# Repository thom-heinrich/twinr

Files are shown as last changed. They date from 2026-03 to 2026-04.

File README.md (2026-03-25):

**WHAT**

*TWINR* is an AI Agent for senior citizens; fully open-source, aiming to make AI accessible to people who would really profit of it. 
*TWINR is heavy WIP, but already working if you do some tinkering. I would love to have new contributors*

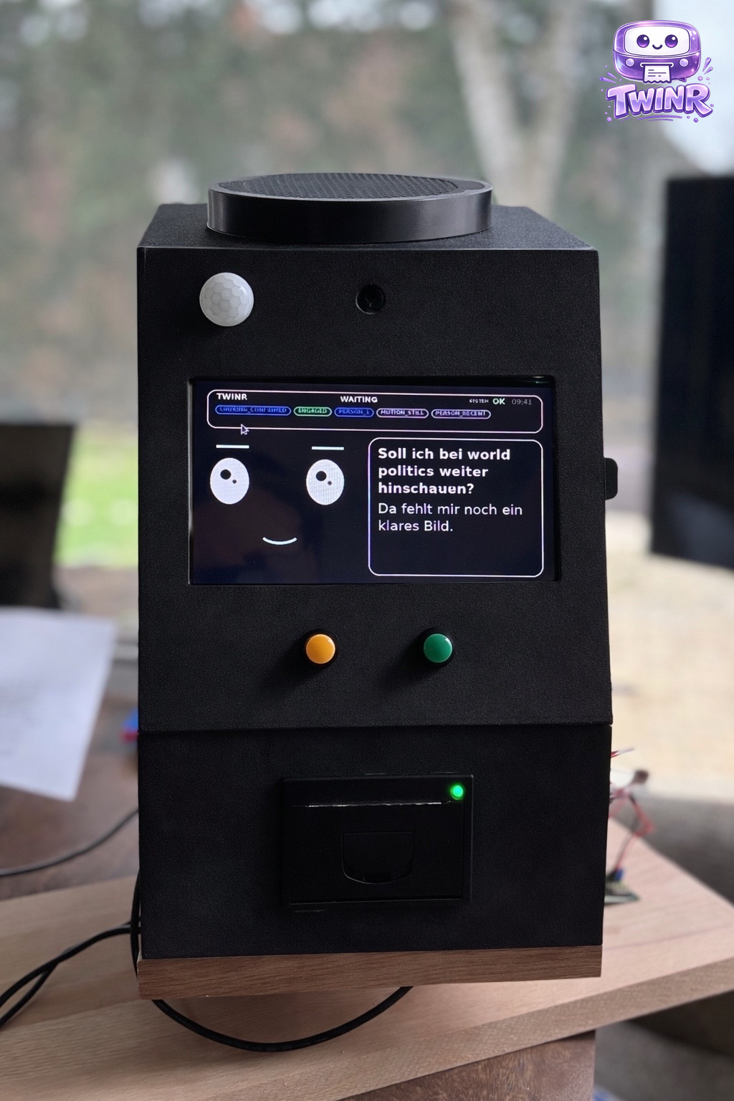
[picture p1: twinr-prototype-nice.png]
twinr-prototype-nice

(You can find the completely unedited picture here --> twinr-prototype.jpeg)

**WHY**

Due to a sad personal event, I spent the last two weeks 24/7 with my mother who is really not tech-savy at all. Okay, tbh - she does not know how to start a computer or use a smart phone - so the web, AI, everything we use daily in our bubble is out of reach to her. 
However: She has so many questions and small tasks an AI Agent could handle easily - plus she loves to use her Alexa, as it is controlled by voice and thus natural to communicate with… but, as we all know, it is limited in it’s capabilities.

**MISSION**

The goal is simple: *Make a voice controlled agent that is as non-digital, as haptic and as accessible as possible*.

**CONTRIBUTE**

So if you are a builder, UX person, maker… and want to join add me on LinkedIn or write to th@arculae.com … if you are not, but you think this is cool, *just share the repo*.

---

**CAPABILITIES**

Twinr is not just a voice wrapper. This repo spans embodied interaction, multimodal perception, memory, automations, integrations, self-programming, operator tooling, and Raspberry-Pi deployment.

- Embodied multi-modal interaction: voice, physical buttons, camera, motion sensing, paper output, display feedback, and optional body movement in one agent stack
- Transcript-first live voice pipeline with follow-up listening, spoken replies, and web-backed question answering
- Physical output layer with speech, thermal printer notes, animated HDMI face UI, and optional servo-based user-following
- Multimodal sensing built around Pi AI Camera, ReSpeaker XVF3800, PIR motion, VAD, and bounded event fusion
- Presence, attention, engagement, and cautious incident cues derived from sensor fusion instead of one-off single-signal hacks
- Proactive companion behaviors that can notice return, stillness, showing intent, or possible distress without defaulting to annoying chatter
- Visual understanding for “look at this” moments, gesture-aware interaction, and camera-assisted embodied UX
- Adaptive memory stack with rolling on-device context, explicit remembered facts, reminders, and optional long-term ChonkyDB memory
- Automation engine for scheduled routines, sensor-triggered actions, printed briefings, and LLM-generated recurring jobs
- Experimental self-programming / Adaptive Skill Engine for compiling reviewed, sandboxed new skills and automations
- Integration-ready architecture for email, calendar, messaging, smart home, and future external systems
- WhatsApp prototype channel plus a broader communications roadmap across TWINR-to-TWINR and TWINR-to-device links
- Caregiver and operator dashboard for devices, memory, automations, system health, logs, and personality management
- Raspberry-Pi hardware operations layer for display, audio, printer, camera, PIR, servo, deployment, and acceptance testing
- Open-source prototype-body 3D-print files and state sound assets included directly in the repo for fast physical iteration

**ROADMAP**

- TWINR App Store with voice discovery and voice-guided installation of reviewed skills
- Real-time TWINR-to-TWINR and TWINR-to-device audio/video communication
- Android and iPhone companion app for family members, caregivers, and operators
- Integration with health trackers and connected health devices
- Proactive companion mode that stays supportive without becoming intrusive or annoying
- Integrated autonomous indoor drone based on Crazyflie for wellbeing checks and other supportive tasks

---

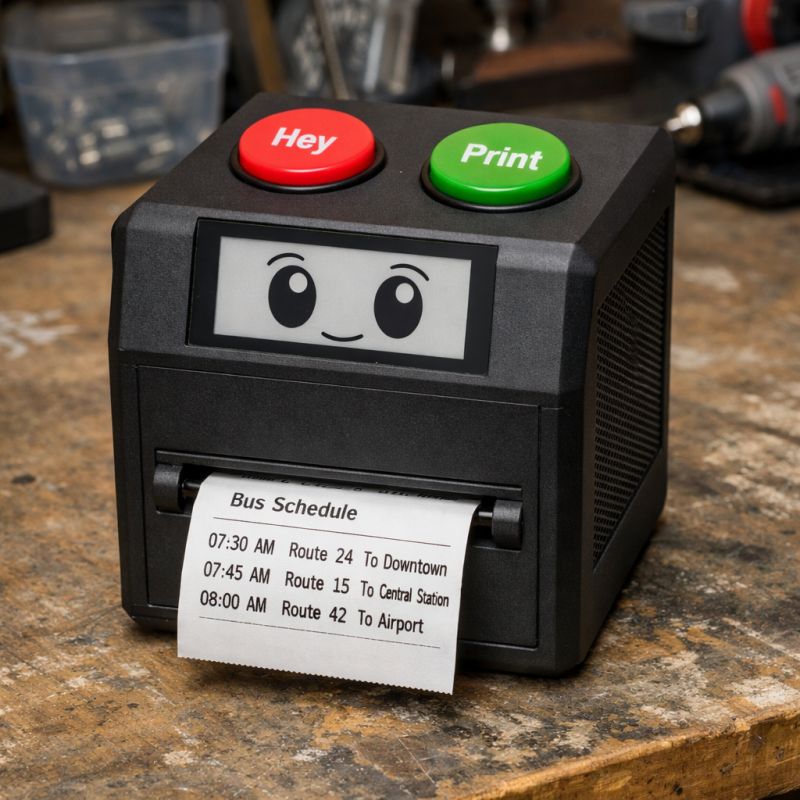
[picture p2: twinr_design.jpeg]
twinr-design


*This is how I imagine TWINR to look in the second or third iteration*

**PROTOTYPE ASSETS**

This repo already includes a few practical prototype assets:

- `3dprint/` contains simple prototype-body parts as `.stl` and `.scad` files, including `main_panel`, `top_panel`, `respeaker`, and `thermal_printer`
- `media/` contains basic state sounds such as `boot.mp3` and `waiting.mp3`

**SHOPPING LIST**

*TWINR Hardware (current prototype direction)*

*Core compute and sensing*

1 x Raspberry Pi 4 or newer

1 x microSD card or SSD for OS, runtime state, and artifacts

1 x Raspberry Pi AI Camera (IMX500) for person, gesture, and presence-related vision

1 x PIR motion sensor with 3.3V-safe GPIO output

2 x buttons (I used 12mm SPST-NO from Same-Sky)

*Audio and feedback*

1 x ReSpeaker XVF3800 4-Mic Array as the main microphone/audio front-end

1 x small speaker compatible with your chosen ReSpeaker playback path

1 x 4" HDMI mini-screen for Twinr's animated face and status UI

1 x thermal printer (DFRobot DFR0503-EN / GP-58-compatible path)

1 x dedicated 9-24V / 2.5A power supply for the thermal printer

*Optional body movement*

1 x digital servo for body rotation; my prototype uses a 360-degree 20 kg model

1 x servo controller / driver, preferably a Pololu Mini Maestro

*Power and build extras*

Optional: a DC-DC converter / buck converter for cleaner power distribution inside the body

Optional: a separate helper Pi if you want to offload the AI-camera or servo path

Plenty of jumper wires, Dupont leads, USB cables, power leads, cable clamps / terminals, and general mounting hardware

Optional: 3D-printed body parts from `3dprint/`

The repo still contains an older Waveshare 4.2" e-paper path for a more minimal build, but the richer current prototype direction is centered on HDMI, Pi AI Camera, ReSpeaker audio, and optional body rotation.

---

**POWER & SAFETY**

For the richer HDMI + camera + audio + printer build, clean power and careful wiring matter a lot more than in the earliest minimal prototype.

- Power the Raspberry Pi through its normal USB-C input with a stable `5V / 3A+` supply
- Give the thermal printer its own `9-24V` supply; do not try to run it from Pi GPIO or weak USB power
- Give a large body servo its own supply matched to the servo vendor spec; do not power a `20kg` servo from the Pi
- If you distribute power inside the body from one larger source, use proper regulators / buck converters for the separate rails instead of improvised direct taps
- Never feed more than `3.3V` into Raspberry Pi GPIO pins
- Share ground where control signals need a common reference, for example Pi and PIR, or Pi / Maestro / servo supply
- Disconnect power before rewiring, double-check polarity before first boot, and secure cables so movement does not pull on GPIO or CSI connectors
- Treat brownouts, random reboots, printer glitches, and twitching servos as likely power-distribution problems first

**HOW TO WIRE**

The current prototype direction is centered on a Raspberry Pi, HDMI mini-screen, ReSpeaker XVF3800 audio, Raspberry Pi AI Camera, two buttons, PIR motion sensing, a thermal printer, and an optional body-rotation servo. The older e-paper path still exists in the repo, but it is no longer the best default for the richer embodied prototype.

See also: [docs/WIRING_DIAGRAM.md](./docs/WIRING_DIAGRAM.md) for a compact Markdown diagram of the current wiring layout.

*1. Prepare the Raspberry Pi*

Install Raspberry Pi OS first. A microSD card is the easiest starting point, though SSD boot also works on recent Pi setups. Before mounting everything into the body, do at least one bench boot with network, keyboard, and screen attached so you can confirm the base system is healthy.

*2. Connect the HDMI mini-screen*

Connect the display to one of the Pi's HDMI outputs with the cable or adapter your screen requires. Many small HDMI screens also need separate `5V` power over USB; if yours does, power it from a suitable regulated `5V` line rather than assuming HDMI alone is enough. Mount the screen so it is readable head-on and leave enough slack in the HDMI cable that opening the body later does not stress the port.

*3. Connect the Raspberry Pi AI Camera*

Connect the Pi AI Camera to the Pi's CSI camera connector with the correct ribbon cable orientation and lock the connector before powering up. Do not hot-plug the camera ribbon. Mount the camera facing forward with a stable field of view, because Twinr uses this path for person, gesture, attention, and presence-related cues.

*4. Connect the ReSpeaker XVF3800 and speaker*

Connect the ReSpeaker XVF3800 to the Pi through its supported USB path so Twinr can use it as the main microphone/audio front-end. Then connect a compatible speaker or powered speaker path for playback. The exact speaker wiring depends on your ReSpeaker board variant: some setups want a powered speaker or small amplifier stage, so do not assume the board can safely drive an arbitrary passive speaker directly. If you prefer, Twinr can also keep ReSpeaker as the microphone path while using a different playback sink such as HDMI audio.

*5. Connect the two buttons*

Use the buttons as simple GPIO inputs with the Pi's internal pull-ups.

Current Twinr mapping:

- Green / "Hey" button: one side to `GPIO23` (`physical pin 16`)
- Yellow / "Print" button: one side to `GPIO22` (`physical pin 15`)
- The other side of both buttons goes to `GND`

No external resistor is required when the software uses the normal pull-up configuration. Do not connect these button inputs to `5V`.

*6. Connect the PIR motion sensor*

Current Twinr prototype mapping:

- `OUT -> GPIO26` (`physical pin 37`)
- `GND -> GND`
- `VCC ->` the supply voltage required by your PIR module

Software defaults assume `active_high=true` and `bias=pull-down`. The signal presented to the Raspberry Pi must stay at or below `3.3V`. If your PIR module is not explicitly GPIO-safe, add level shifting before connecting it to the Pi.

*7. Connect the thermal printer*

For the current printer path, connect the DFRobot `DFR0503-EN` to the Pi over USB and power it from its own external `9-24V / 2.5A` supply. Keep printer power physically separate from the Pi's GPIO power pins. USB carries the data path; the external supply handles the real heating and paper feed load.

*8. Optional: connect the body-rotation servo*

There are two practical paths:

- Preferred path: use a `Pololu Mini Maestro` as the servo controller. Connect the Maestro to the Pi over USB, switch it into `USB_DUAL_PORT`, then connect the servo to the Maestro rather than directly to the Pi. Power the servo from its own supply matched to the servo's requirements.
- Simpler direct path: connect servo `SIG -> GPIO18` (`physical pin 12`), `GND -> GND`, and `V+ ->` the servo supply recommended by the vendor. This is workable for direct experiments, but the calmer hardware path is usually the external controller.

If you use an external servo supply, keep a common ground between the control side and the servo side. For continuous-rotation or high-torque servos, bench-test motion before mounting the mechanism into the body.

*9. First bring-up and configuration*

After wiring, configure and smoke-test each subsystem separately before closing the body:

```bash
cd /twinr
sudo hardware/display/setup_display.sh --env-file /twinr/.env --driver hdmi_wayland
sudo hardware/mic/setup_audio.sh --env-file /twinr/.env --test
sudo hardware/mic/setup_respeaker_access.sh
hardware/buttons/setup_buttons.sh --green 23 --yellow 22
hardware/pir/setup_pir.sh --motion 26 --probe
sudo hardware/printer/setup_printer.sh --default --test
python3 hardware/piaicam/smoke_piaicam.py
sudo hardware/servo/setup_pololu_maestro.sh
```

That staged approach is worth the time. It makes it much easier to catch a bad GPIO mapping, weak power rail, loose camera ribbon, muted audio path, or wrong printer polarity before everything is buried inside the enclosure.

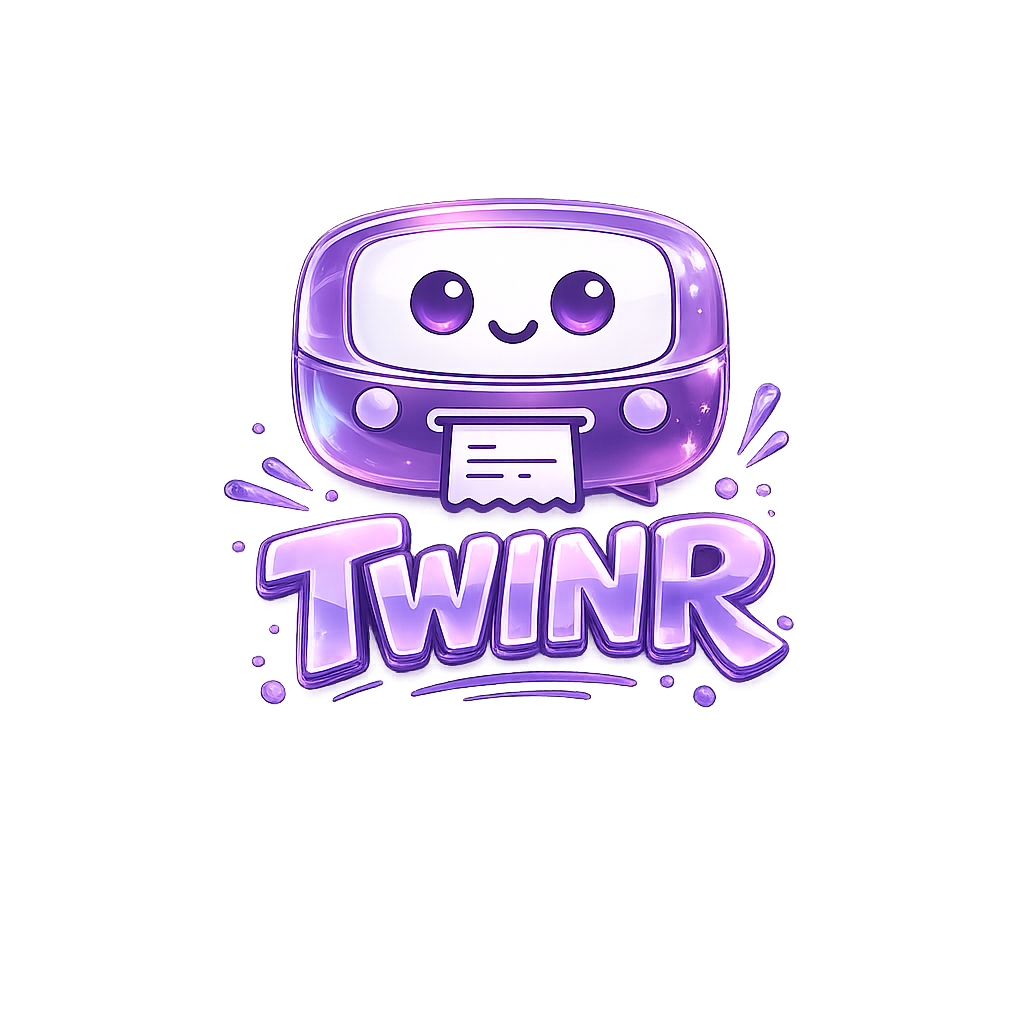
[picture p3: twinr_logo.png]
twinr-logo


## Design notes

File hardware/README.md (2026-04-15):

# hardware

Pi-side setup, probe, and smoke-test scripts for Twinr peripherals.

## Responsibility

`hardware` owns:
- persist Raspberry Pi hardware settings into Twinr env files and OS config
- install vendor or system dependencies for display, audio, and printer paths
- install and stage vendor prerequisites for optional Bitcraze Crazyradio/Crazyflie experimentation under an isolated runtime workspace
- install or stage Pi-side productive systemd units for authoritative runtime supervision and the web portal
- install or stage the development-host bounded drone daemon that exposes Twinr's mission-level inspection surface behind preflight and manual-arm gates
- keep only the productive hardware/bootstrap surface in the tracked tree; retired helper-Pi proxy artifacts now live under `__legacy__/hardware/ops/`
- stage low-level Pi-side kernel or OS integration code when a peripheral needs a real kernel-facing driver path instead of a userspace helper
- run bounded manual probes for buttons, PIR motion, display, and printer setup
- run the end-to-end acceptance deploy command that mirrors the leading repo to the Pi, syncs productive runtime settings, restarts services, and verifies post-restart health

`hardware` does **not** own:
- runtime device adapters in `src/twinr/hardware` or `src/twinr/display`
- main Twinr loop orchestration or user-facing behavior policy
- direct runtime-only fixes in `/twinr` without leading-repo changes here first

## Key files

| File | Purpose |
|---|---|
| [buttons/](./buttons) | Button setup and GPIO probe |
| [display/](./display) | Display backend setup and smoke tests |
| [bitcraze/](./bitcraze) | Crazyradio USB access, pinned firmware staging, isolated `/twinr/bitcraze` workspace provisioning, and the fail-closed Crazyflie firmware build/promotion/flash helpers |
| [mic/](./mic) | Audio default-device setup, playback loudness normalization/softvol, and XVF3800 USB-access rule |
| [servo/](./servo) | Pololu Maestro USB access, `USB_DUAL_PORT` setup, and operator hold/arm state control for Twinr's continuous attention-servo runtime |
| [ops/](./ops) | Pi-side productive systemd units, the development-host bounded drone daemon, and Pi/bootstrap deploy helpers |
| [piaicam/](./piaicam) | Pi AI Camera smoke tests, custom gesture dataset capture, and MediaPipe model staging/training |
| [pir/](./pir) | PIR setup and motion probe |
| [printer/](./printer) | Thermal-printer CUPS setup |
| [servo_kernel/](./servo_kernel) | Out-of-tree Raspberry Pi servo kernel module plus low-level C acceptance tool for calm body-motion probes, including persisted last-target safety between bounded runs |
| [component.yaml](./component.yaml) | Structured directory metadata |
| [AGENTS.md](./AGENTS.md) | Local editing rules |

Retired standalone break-glass units now live only under the ignored top-level `__legacy__/` workspace folder when needed locally; they are no longer part of the tracked hardware tree.

## Usage

```bash
./hardware/buttons/setup_buttons.sh --env-file .env --green 23 --yellow 22 --probe
python3 hardware/display/display_test.py --env-file .env
sudo ./hardware/bitcraze/setup_bitcraze.sh --workspace /twinr/bitcraze --runtime-user thh
python3 hardware/bitcraze/probe_crazyradio.py --workspace /twinr/bitcraze
bash hardware/bitcraze/build_on_device_failsafe.sh --firmware-root /tmp/crazyflie-firmware --expected-firmware-revision 2025.12.1
/twinr/bitcraze/.venv/bin/python hardware/bitcraze/flash_on_device_failsafe.py --lane dev --device-role dev --attestation hardware/bitcraze/twinr_on_device_failsafe/build/twinr_on_device_failsafe.build-attestation.json
sudo ./hardware/mic/setup_audio.sh --env-file .env --proactive-device-match reSpeaker --test
sudo ./hardware/mic/setup_respeaker_access.sh
sudo ./hardware/servo/setup_pololu_maestro.sh
python3 hardware/servo/attention_servo_state.py status
python3 hardware/piaicam/fetch_mediapipe_models.py
python3 hardware/piaicam/import_public_seed_dataset.py --count-per-label 128
python3 hardware/piaicam/capture_custom_gesture_dataset.py --label none --count 24
python3 hardware/piaicam/capture_custom_gesture_dataset.py --label peace_sign --count 40 --interval-s 0.35
python3 hardware/piaicam/smoke_piaicam.py --profile quick
state/mediapipe/model_maker_venv/bin/python hardware/piaicam/train_custom_gesture_model.py --dataset-root state/mediapipe/custom_gesture_dataset --dry-run
python3 hardware/ops/install_whatsapp_node_runtime.py
python3 hardware/ops/bootstrap_self_coding_pi.py
python3 hardware/ops/drone_daemon.py --pose-provider stub_ok --bind 127.0.0.1 --port 8791
python3 hardware/ops/watch_pi_repo_mirror.py --once
python3 hardware/ops/deploy_pi_runtime.py --live-text "Antworte nur mit: ok."
```

Legacy helper-Pi proxy install commands are intentionally omitted from the main
usage path. Current Twinr runtime wiring is single-Pi; the historical proxy
artifacts now live only under `__legacy__/hardware/ops/`.

## See also

- [component.yaml](./component.yaml)
- [AGENTS.md](./AGENTS.md)
- [Runtime hardware package](../src/twinr/hardware/README.md)
- [Runtime display package](../src/twinr/display/README.md)

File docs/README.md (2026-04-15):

# Twinr

Twinr is a minimal digital, maximal haptic, senior-citizen-optimized physical AI agent.

The product is designed around simple physical interaction instead of app-first complexity. A user presses a green button, speaks naturally, and Twinr listens until a short pause is detected. Twinr then transcribes the utterance with a speech-to-text provider, sends the result to a foundation model, performs agentic tasks when needed, and answers via text-to-speech. A yellow button prints the latest answer as a short, easy-to-read thermal receipt.

Twinr also uses a small status display with animated eyes to communicate its current state: waiting, listening, processing, answering, printing, and error. A small footer line under the face shows a calm device-health summary such as `Betrieb ok`, `warm`, or `Achtung`.

## Core principles

- Minimal digital overhead
- Maximum tactile clarity
- Senior-friendly interaction model
- Fast feedback through buttons, voice, display, and paper
- Configurable AI behavior without exposing technical complexity

## Interaction model

### Voice interaction

1. User presses the green button
2. Twinr starts listening
3. Twinr stops listening after a short speech pause
4. Twinr sends audio to an STT provider
5. Twinr processes the request with a foundation model
6. Twinr optionally executes agentic workflows and tool-enabled tasks
7. Twinr speaks the answer via a TTS provider

### Print interaction

1. User presses the yellow button
2. A meta-LLM reformats the most recent answer into a short print-friendly version
3. Twinr prints the result on the thermal printer

## Status display

Twinr uses a display with two eyes to express state in a simple, low-cognitive-load way.

Supported states:

- Waiting
- Listening
- Processing
- Answering
- Printing
- Error

## Memory model

### On-device memory

Twinr keeps a short rolling conversation memory on-device by default. The active short-term schema is structured, not just a flat transcript:

- `raw_tail` keeps the most recent verbatim user/assistant turns
- `ledger` keeps compacted summaries and typed durable notes
- `search_results` stores recent web lookups as first-class entries
- `state` tracks the active topic, last user goal, pending printable, and open loops

When the tail grows beyond the configured cap, Twinr compacts older turns into the ledger and keeps only the newest conversational tail for replay.

By default, the live runtime snapshot is persisted to `state/runtime-state.json` instead of `/tmp`, so the local dashboard and restart flow can restore structured state after bounded restarts.

Durable remembered facts that the user explicitly asks Twinr to keep are written to `state/MEMORY.md`. This file is separate from the rolling runtime snapshot and is only meant for explicit “remember this” items, not every turn.

Scheduled reminders and timers are stored separately in `state/reminders.json`. The voice agent writes to this store only via the reminder tool, and the idle loops deliver due reminders later with bounded retry handling if speech output fails.

Basic local automations are stored in `state/automations.json`. This store is meant for explicit operator-created rules and covers two trigger families today: time-based schedules and simple if-then rules over named facts/events.

The active voice agent now exposes a dedicated automation toolset for:

- listing existing automations
- creating time-based automations
- creating sensor-triggered automations
- updating time-based automations
- updating sensor-triggered automations
- deleting automations

Twinr also exposes a bounded self-settings tool for a few operator-safe runtime changes. Today that includes:

- recent-memory capacity
- speaking pause detection
- follow-up listening window
- spoken voice
- spoken speed

Voice and speed changes are persisted back into `.env`, applied live to the running backend configuration, and kept within a narrow range so the device stays calm and understandable.

Twinr keeps a small curated spoken-voice catalog for this path instead of exposing every possible provider voice. That lets the live voice agent answer questions like “Which voices do you have?” and map descriptive requests such as “use a male voice” or “sound warmer” onto a bounded `spoken_voice` setting without opening up the whole provider surface.

Twinr also keeps a small bounded adaptive timing profile in `state/adaptive_timing.json`. This profile learns slowly from real button turns:

- no-speech timeouts widen the next start-of-speech window
- resumed speech during a pause grace window increases pause tolerance
- repeated clean, fast starts slowly tighten the timing again

The adaptive layer is intentionally conservative. It never removes the hard timing bounds, and it stays anchored to the configured base values so the device remains predictable.

Time-based automations can either:

- speak static text
- print static text
- generate spoken content from an LLM prompt
- generate printed content from an LLM prompt

For scheduled live-information jobs such as daily weather, daily news, or printed headlines, Twinr stores the automation as an `llm_prompt` action with web search enabled and executes it later from the idle loop.

Separately from those operator-configured automations, the idle loop now owns one explicit nightly orchestration pass. That pass stays silent at night, flushes long-term/background writers, refreshes world intelligence, prepares a morning digest artifact, and then prepares the next reserve-lane day plan so the morning runtime can start from durable overnight state instead of scattered background side effects.

Sensor-triggered automations currently support the following operator-facing trigger kinds:

- `pir_motion_detected`
- `pir_no_motion` with a required hold duration
- `vad_speech_detected`
- `vad_quiet` with a required hold duration
- `camera_person_visible`
- `camera_hand_or_object_near_camera`

The proactive monitor now feeds stable PIR, camera, and VAD facts into the automation engine while Twinr is idle. This lets voice-created if-then automations react to sensor facts without exposing raw camera frames or raw audio chunks as tool-level inputs.
The target-state map for what Twinr should try to derive from PIR, audio, and camera lives in [`SENSOR_FUSION.md`](SENSOR_FUSION.md).
The runtime-layer model for separating local `near_device_presence` from optional smart-home `room_context` and `home_context` lives in [`SMART_HOME_RUNTIME_CONTEXT_MODEL_V1.md`](SMART_HOME_RUNTIME_CONTEXT_MODEL_V1.md).
The short-window rolling-buffer and multimodal event-fusion design for deriving stable `2-8s` event claims from audio plus camera history lives in [`MULTIMODAL_EVENT_FUSION_V1.md`](MULTIMODAL_EVENT_FUSION_V1.md).
The room-agnostic long-horizon smart-home profiling design for motion sensors now lives in [`SMART_HOME_ENVIRONMENT_PROFILE_V1.md`](SMART_HOME_ENVIRONMENT_PROFILE_V1.md). That document defines how Twinr should learn behavior patterns from environment nodes, transitions, fragmentation, and timing without assuming that any sensor belongs to a known room.
The ReSpeaker-specific requirements and build checklist for turning the XVF3800 into a first-class Twinr sensor live in [`RESPEAKER_REQUIREMENTS.md`](RESPEAKER_REQUIREMENTS.md).
The camera-side output contract for later runtime integration lives in [`AI_CAMERA_INTEGRATION_CONTRACT.md`](AI_CAMERA_INTEGRATION_CONTRACT.md). That contract now separates `body_pose`, `motion`, `coarse_arm_gesture`, and `fine_hand_gesture` explicitly so Twinr can keep realistic V1 camera requirements and stricter V2 hand-gesture ambitions apart.
The current fine-hand-gesture evaluation and recommendation path lives in [`AI_CAMERA_FINE_HAND_GESTURE_PATH.md`](AI_CAMERA_FINE_HAND_GESTURE_PATH.md).
The currently accepted Raspberry Pi gesture runtime freeze point lives in [`PI_GESTURE_BASELINE.md`](PI_GESTURE_BASELINE.md). That document records the exact low-light, MediaPipe, ROI, and HDMI ack values that are currently accepted on `/twinr`.

Explicit requests to change future user-profile context or future speaking/behavior rules are written into managed sections inside `personality/USER.md` and `personality/PERSONALITY.md`. Twinr reloads those files on the next provider request instead of baking them permanently into code.
The target-state design for a richer persistent Twinr self now lives in [`persistent_personality_architecture.md`](persistent_personality_architecture.md). That document separates stable core character, relational user model, place intelligence, world intelligence, and bounded reflective evolution instead of treating personality as one growing prompt blob.

### Long-term memory (optional)

Twinr can optionally be extended with a ChonkyDB-based long-term memory layer. This provides durable storage of information in a combined index spanning:

- Vector search
- Graph relationships
- Full-text search
- Hash-based lookup
- Temporal access patterns

This long-term layer is intended for persistent user preferences, recalled facts, and historical conversations.

Twinr now includes a small external client baseline under `src/twinr/memory/chonkydb/`. The current basics cover instance/auth inspection, record listing, single-record fetches, full-document fetches, unified retrieval queries, single/bulk record submissions, a versioned `twinr_graph` schema v1 with namespaced typed edges for structured relationships, and a first local personal-graph layer for contacts, preferences, plans, and contact clarification.

The runtime orchestration for this path now lives separately under `src/twinr/memory/longterm/`. That layer builds a small structured long-term provider context before each turn and can persist episodic conversation memories in the background after a turn finishes, so recall can improve without blocking the response path.

The canonical Twinr env names for that path are:

- `TWINR_LONG_TERM_MEMORY_ENABLED`
- `TWINR_LONG_TERM_MEMORY_BACKEND`
- `TWINR_LONG_TERM_MEMORY_PATH`
- `TWINR_CHONKYDB_BASE_URL`
- `TWINR_CHONKYDB_API_KEY`
- `TWINR_CHONKYDB_API_KEY_HEADER`
- `TWINR_CHONKYDB_ALLOW_BEARER_AUTH`
- `TWINR_CHONKYDB_TIMEOUT_S`

For migration convenience, the config also accepts legacy `CCODEX_MEMORY_BASE_URL` and `CCODEX_MEMORY_API_KEY` as fallbacks, but Twinr docs and code should refer to the backend as `chonkydb`.

Externally readable ChonkyDB incident and operator-facing status reports now live
under `docs/chonkydb/ext/`. These reports are written to be understandable without
access to Twinr's internal artifact stores and are the right place for self-contained
handoffs to ChonkyDB admins.

## Web interface

Twinr exposes a web interface on port `1337` for local configuration.

Example configuration areas:

- Personality and tone
- User preferences
- Automations
- Provider selection
- Device settings
- Memory settings
- Print behavior
- Display settings

The web interface should stay simple enough for caregivers, family members, or operators to maintain without developer tooling.

The current implementation uses a server-rendered local dashboard with these sections:

- Dashboard
- Devices
- LLM Usage
- System Health
- Automations
- Personality
- Memory
- Connect
- Settings
- User

The `Memory` page reads a live runtime snapshot from the active Twinr process, so operators can inspect the current on-device conversation memory without attaching to the running loop.
The `Memory` page also exposes the durable `state/MEMORY.md` store, so operators can inspect and add explicit long-lived remembered items without touching the rolling runtime snapshot.
The same `Memory` page now exposes scheduled reminders from `state/reminders.json`, including pending and delivered reminders plus simple operator controls to add, complete, or delete reminder entries.
The `Settings` page now also shows the live bounded adaptive listening profile from `state/adaptive_timing.json`, including the learned start-of-speech and pause windows plus a manual reset action.
The `Automations` page reads `state/automations.json`, groups stored rules by automation family, and exposes explicit create/edit/delete controls for scheduled and sensor-triggered rules. Integration modules now register their own reserved family blocks through an integration-side registry, so later mail/calendar/integration automations can land in their own UI sections without rewriting the core page.
The `Personality` and `User` pages now separate the hand-written base text from Twinr-managed updates, so tool-written behavior/profile changes stay visible and editable without clobbering the base files.
The `Devices` page shows the current local hardware view for printer, camera, audio, PIR, and buttons, plus the newest self-test evidence Twinr can confirm. Signals that the current path cannot expose, such as paper status on the raw USB printer path, are shown as unknown instead of guessed.
The `LLM Usage` page reads the local usage store for tracked OpenAI calls, including model names, request ids, and token counts when the provider returns them.
The `System Health` page reads live Raspberry Pi metrics and Twinr worker presence so caregivers can see whether the box itself looks healthy.
The `Ops Logs` page reads the persistent local event log under `artifacts/stores/ops/events.jsonl`, including proactive observation changes, proactive trigger detections, and spoken proactive prompts.
The `Voice Profile` page manages a local-only speaker template. Phase 1 uses the normal conversation microphone only, stores no raw enrollment audio, and exposes only a soft confidence signal such as `likely user`, `uncertain`, or `unknown voice`. Support bundles omit the live voice-assessment fields.
In realtime voice mode, Twinr can now also manage that profile by spoken request: it can enroll the current spoken turn into the local voice profile, read the current profile status, or reset the profile when the user explicitly asks for it.
The live speaker signal is injected into the LLM context as a short redacted system hint, not as raw audio or a biometric template. When the signal is `uncertain` or `unknown voice`, Twinr now asks for extra confirmation before persistent changes such as saved memory/profile/personality updates or automation changes.
The planned multimodal replacement for that voice-only confirmation path is documented in `docs/PRIVACY_AUTH_POLICY_V1.md`.
The external browser benchmark integration plan for AgentLab, BrowserGym, and WebArena-Verified is documented in `docs/BROWSERGYM_AGENTLAB_WEB_ARENA_VERIFIED_PLAN.md`.

## High-level architecture

### Inputs

- Green hardware button
- Yellow hardware button
- PIR motion sensor input
- Microphone audio
- Web configuration UI

### Outputs

- Speaker audio
- Thermal printer output
- Eye display status
- Local web interface

### Service layers

- Speech-to-text provider layer
- Foundation model / agent layer
- Optional bounded drone mission layer for inspect-only planning against a separate drone daemon
- Text-to-speech provider layer
- Memory layer
- Hardware abstraction layer
- Web configuration layer

## Repository layout

- `docs/` — documentation and structured specifications
- `docs/providers/` — provider-specific notes and setup guides
- `hardware/` — Raspberry Pi setup scripts for buttons, PIR, audio, printer, and display hardware
- `hardware/ops/drone_daemon.py` — development-host bounded drone daemon that owns mission preflight, manual-arm, and the first stationary-observe inspection slice
- `personality/` — prompt-context files for system, user, and assistant style
- `state/` — runtime-generated persistent snapshot and durable remembered facts (`gitignored`)
- `src/twinr/agent/` — runtime orchestration, state machine, and hardware workflows
- `src/twinr/display/` — Waveshare display wrapper and image rendering helpers
- `src/twinr/providers/` — provider implementations such as OpenAI
- `src/twinr/memory/` — on-device memory, durable memory stores, and reminders
- `src/twinr/memory/chonkydb/` — external ChonkyDB client basics plus versioned Twinr graph schema for future long-term memory integration
- `src/twinr/memory/longterm/` — long-term retrieval and non-blocking persistence orchestration
- `src/twinr/automations/` — canonical automation definitions, evaluation, and persistent CRUD store
- `src/twinr/hardware/` — audio, button, PIR, camera, and printer adapters
- `state/voice_profile.json` — local speaker-template store for the optional voice-confidence layer
- `test/` — tests and validation assets

## Intended user experience

Twinr should feel calm, obvious, and trustworthy. A user should not need to understand models, APIs, sessions, prompts, or configuration details. The interaction should feel closer to using a helpful household object than using a computer.

## Current scope

This repository defines the foundation for:

- Button-driven voice capture
- Passive PIR motion sensing for local hardware bring-up and future presence-aware behavior
- Optional body-orientation follow through a bounded Pi servo output fed by the existing multimodal attention target
- A stateful social-trigger engine for cautious presence, attention, and safety nudges
- Provider-based STT / LLM / TTS orchestration
- Optional bounded drone inspection planning through a separate mission daemon with manual-arm-only safety defaults
- Agentic task execution
- Paper-based answer printing
- Visual state feedback through eyes
- On-device memory with optional long-term expansion
- Local web-based configuration on `:1337`

## Hardware bootstrap

For one compact current-build overview, see [WIRING_DIAGRAM.md](./WIRING_DIAGRAM.md).

### Buttons

The current Raspberry Pi setup does not expose the physical Twinr buttons as dedicated Linux input devices. They should be handled as GPIO lines on `gpiochip0`.

Persist the current mapping with:

```bash
cd /twinr
hardware/buttons/setup_buttons.sh --green 23 --yellow 22
```

Probe the configured buttons with:

```bash
cd /twinr
./.venv/bin/python hardware/buttons/probe_buttons.py --env-file /twinr/.env --configured --duration 15
```

The runtime-facing GPIO helpers live in `src/twinr/hardware/buttons.py`.

### PIR motion sensor

Twinr now supports a dedicated PIR motion input for hardware validation and future presence-aware behavior.

Persist the current prototype mapping with:

```bash
cd /twinr
hardware/pir/setup_pir.sh --motion 26 --probe
```

Probe the configured PIR input with:

```bash
cd /twinr
./.venv/bin/python hardware/pir/probe_pir.py --env-file /twinr/.env --duration 30
```

The current prototype wiring is:

- `OUT -> GPIO26` on the Pi (`physical pin 37`, often labeled `IO26`)
- `GND -> GND`
- `VCC ->` the voltage required by the PIR module

Software defaults assume `active_high=true` and `bias=pull-down`. The GPIO signal presented to the Pi must stay at or below `3.3V`.

The runtime-facing PIR helpers live in `src/twinr/hardware/pir.py`.

### Attention servo

Twinr can optionally drive one body-orientation servo from the same conservative
multimodal `attention_target` that already powers HDMI eye-follow. The servo
path does not choose its own target; it only turns a normalized left/right
target into bounded servo pulse widths.

The current prototype wiring uses:

- `SIG -> GPIO18` on the Pi (`physical pin 12`, often labeled `IO18`)
- `GND -> GND`
- `V+ ->` the servo supply recommended by the servo module vendor

Recommended runtime env knobs:

- `TWINR_ATTENTION_SERVO_ENABLED=true`
- `TWINR_ATTENTION_SERVO_DRIVER=auto`
- `TWINR_ATTENTION_SERVO_GPIO=18`
- `TWINR_ATTENTION_SERVO_INVERT_DIRECTION=false`

Direction check:
If a person appears on the right side of the camera image and Twinr physically turns left instead of right, the mechanical mount is inverted relative to camera space and `TWINR_ATTENTION_SERVO_INVERT_DIRECTION=true` is required.

Twinr's productive servo path is now single-Pi only: the attention-servo
output must live on the main Pi. The active config loader rejects the retired
helper-Pi `peer_pololu_maestro` / `TWINR_ATTENTION_SERVO_PEER_BASE_URL`
topology instead of letting it silently revive.

Optional tuning knobs:

- `TWINR_ATTENTION_SERVO_TARGET_HOLD_S`
- `TWINR_ATTENTION_SERVO_LOSS_EXTRAPOLATION_S`
- `TWINR_ATTENTION_SERVO_LOSS_EXTRAPOLATION_GAIN`
- `TWINR_ATTENTION_SERVO_MIN_CONFIDENCE`
- `TWINR_ATTENTION_SERVO_HOLD_MIN_CONFIDENCE`
- `TWINR_ATTENTION_SERVO_DEADBAND`
- `TWINR_ATTENTION_SERVO_MIN_PULSE_WIDTH_US`
- `TWINR_ATTENTION_SERVO_CENTER_PULSE_WIDTH_US`
- `TWINR_ATTENTION_SERVO_MAX_PULSE_WIDTH_US`
- For wide-angle positional servos, set these to the servo datasheet range instead of
  leaving them at a narrower generic calibration. A DS3225-class 270 degree servo
  typically expects a full `500-2500 us` positional range with `1500 us` center.
- `TWINR_ATTENTION_SERVO_MAX_STEP_US`
- `TWINR_ATTENTION_SERVO_TARGET_SMOOTHING_S`
- `TWINR_ATTENTION_SERVO_MAX_VELOCITY_US_PER_S`
- `TWINR_ATTENTION_SERVO_MAX_ACCELERATION_US_PER_S2`
- `TWINR_ATTENTION_SERVO_MAX_JERK_US_PER_S3`
- `TWINR_ATTENTION_SERVO_MIN_COMMAND_DELTA_US`
- `TWINR_ATTENTION_SERVO_VISIBLE_RETARGET_TOLERANCE_US`
- `TWINR_ATTENTION_SERVO_VISIBLE_RETARGET_COOLDOWN_S`
- `TWINR_ATTENTION_SERVO_IDLE_RELEASE_S`
- `TWINR_ATTENTION_SERVO_SETTLED_RELEASE_S`
- `TWINR_ATTENTION_SERVO_FOLLOW_EXIT_ONLY`
- `TWINR_ATTENTION_SERVO_VISIBLE_RECENTER_INTERVAL_S`
- `TWINR_ATTENTION_SERVO_VISIBLE_RECENTER_CENTER_TOLERANCE`
- `TWINR_ATTENTION_SERVO_MECHANICAL_RANGE_DEGREES`

If visible follow is directionally correct but still fidgets after each step,
increase `TWINR_ATTENTION_SERVO_VISIBLE_RETARGET_TOLERANCE_US` and/or set a
small `TWINR_ATTENTION_SERVO_VISIBLE_RETARGET_COOLDOWN_S` so the head briefly
holds after a real move before it accepts another same-side micro-retarget.
- `TWINR_ATTENTION_SERVO_EXIT_FOLLOW_MAX_DEGREES`
- `TWINR_ATTENTION_SERVO_EXIT_ACTIVATION_DELAY_S`
- `TWINR_ATTENTION_SERVO_CONTINUOUS_MAX_SPEED_DEGREES_PER_S`
- `TWINR_ATTENTION_SERVO_CONTINUOUS_SLOW_ZONE_DEGREES`
- `TWINR_ATTENTION_SERVO_CONTINUOUS_STOP_TOLERANCE_DEGREES`
- `TWINR_ATTENTION_SERVO_CONTINUOUS_MIN_SPEED_PULSE_DELTA_US`
- `TWINR_ATTENTION_SERVO_CONTINUOUS_MAX_SPEED_PULSE_DELTA_US`
- `TWINR_ATTENTION_SERVO_STATE_PATH`
- `TWINR_ATTENTION_SERVO_ESTIMATED_ZERO_MAX_UNCERTAINTY_DEGREES`
- `TWINR_ATTENTION_SERVO_ESTIMATED_ZERO_SETTLE_TOLERANCE_DEGREES`
- `TWINR_ATTENTION_SERVO_ESTIMATED_ZERO_SPEED_SCALE`
- `TWINR_ATTENTION_SERVO_ESTIMATED_ZERO_MOVE_PULSE_DELTA_US`
- `TWINR_ATTENTION_SERVO_ESTIMATED_ZERO_MOVE_PERIOD_S`
- `TWINR_ATTENTION_SERVO_ESTIMATED_ZERO_MOVE_DUTY_CYCLE`
- `TWINR_ATTENTION_SERVO_CONTINUOUS_RETURN_TO_ZERO_AFTER_S`

Supported driver values are `auto`, `twinr_kernel`, `sysfs_pwm`, `pigpio`,
`lgpio_pwm`, `lgpio`, and `pololu_maestro`.

When `TWINR_ATTENTION_SERVO_DRIVER=auto`, Twinr first probes for the custom
`/sys/class/twinr_servo/servo0` kernel-module contract, then a usable
kernel-PWM sysfs path, then a usable hardware-timed `pigpio` path, and only
falls back to `lgpio_pwm` before the older `lgpio` servo helper. The
`twinr_kernel` path is the preferred senior-facing option when the out-of-tree
Twinr kernel servo module is built and loaded on the Pi.

`pololu_maestro` expects the Maestro command port to exist locally on the same
host as the Twinr runtime.

For calm physical behavior, do not think only in terms of "smaller pulse
steps". Many hobby servos have a pulse dead band, so tiny frequent pulse
changes can buzz or twitch instead of looking softer. Twinr therefore combines:

- attention-target smoothing
- short exit-trajectory extrapolation, so the body can keep following briefly in the user's leaving direction instead of freezing or snapping back the moment the camera loses them
- an exit-activation delay, so brief camera dropouts do not immediately trigger a body turn
- hard velocity limits
- acceleration and jerk limits in pulse space
- a small command threshold so sub-dead-band plan noise is not emitted as GPIO churn
- release-after-settle on stable off-center targets, so a loaded servo can move into place and then relax instead of audibly holding torque forever
- optional exit-only follow, so Twinr stays physically still while a person remains in frame, cancels exit-follow immediately when any person is visible again, and only turns gently along the departure trajectory up to one configured off-center degree limit before releasing the servo again

Keep the servo signal at `3.3V` logic level on the Pi side, and power the
servo from a supply that matches the specific servo module instead of feeding
it from a weak GPIO pin.

In continuous-rotation mode, Twinr cannot read an absolute shaft angle back
from the servo. The controller therefore treats the physically current pose at
startup as virtual `0°`. If an operator hand-sets a forward-facing neutral
pose, start or restart the runtime only after that pose is in place.

Twinr now persists that virtual heading in `TWINR_ATTENTION_SERVO_STATE_PATH`.
When the persisted state says `hold_until_armed`, startup keeps the continuous
servo output released and returns `manual_hold` instead of immediately
leaving the operator-set `0°` pose. Operators can flip that persisted
continuous-servo state explicitly with `python3 hardware/servo/attention_servo_state.py`
using `hold-current-zero`, `hold`, `arm`, and `return-to-estimated-zero`.

`return-to-estimated-zero` is still open-loop, but it no longer starts from a
generic recenter pulse when a real movement journal exists. Twinr now persists
the bounded outbound movement path from the operator-defined `0°` and, on
return, replays those logged segments in reverse with inverse pulse widths
before falling back to the older estimated-zero planner. Those replay segments
now run through an exact bounded segment player that disables each pulse at
its recorded deadline instead of holding it until the next runtime update
tick. That makes return-to-zero track the actual commanded path instead of
quantizing short segments into longer physical moves. Twinr still keeps a
persisted `heading_uncertainty_degrees`
alongside that journal and rejects the return request once the saved
uncertainty exceeds
`TWINR_ATTENTION_SERVO_ESTIMATED_ZERO_MAX_UNCERTAINTY_DEGREES`. When no
journal is available, the fallback planner still uses its own tighter zero-
settle threshold instead of the broader live-tracking tolerance:
`TWINR_ATTENTION_SERVO_ESTIMATED_ZERO_SETTLE_TOLERANCE_DEGREES`. Because the
gentle fallback return pulses can move the real hardware more slowly than the
normal follow model expects, `TWINR_ATTENTION_SERVO_ESTIMATED_ZERO_SPEED_SCALE`
lets the virtual heading decay more conservatively during return-to-zero.
That fallback slow return is gated through move/release phases:
`TWINR_ATTENTION_SERVO_ESTIMATED_ZERO_MOVE_PULSE_DELTA_US`
caps each movement pulse near neutral, while
`TWINR_ATTENTION_SERVO_ESTIMATED_ZERO_MOVE_PERIOD_S` plus
`TWINR_ATTENTION_SERVO_ESTIMATED_ZERO_MOVE_DUTY_CYCLE` determine how long each
slow nudge should stay active before Twinr releases the output again on the
next servo update.
For ordinary live tracking on a continuous servo, keep
`TWINR_ATTENTION_SERVO_TARGET_HOLD_S` short so only brief tracker dropouts are
projected. If Twinr should wait before drifting back to the persisted `0°`,
use `TWINR_ATTENTION_SERVO_CONTINUOUS_RETURN_TO_ZERO_AFTER_S` instead. That
separate no-user timer keeps the output released during absence and only starts
the slow return-to-zero path after the configured delay has elapsed.
If the visible target stays stable but its confidence bounces around the main
acquisition threshold, `TWINR_ATTENTION_SERVO_HOLD_MIN_CONFIDENCE` lets Twinr
keep following the already-visible track at a lower release threshold instead
of snapping into `recentering` on every short confidence dip.
For active visible follow on a continuous servo, Twinr now closes the loop on
the live image offset itself and maps that error only into the configured
continuous min/max speed pulse window. The persisted virtual heading remains
for journaling and return-to-zero, but active follow no longer routes through
the virtual-heading target calculation that can oscillate at sparse Pi refresh
cadence.
When the continuous-servo path is already at the estimated `0°`, Twinr now
keeps the output released in idle instead of sending a nominal center pulse
that could still drift a real 360-degree servo off the operator-set neutral.

### Social trigger engine

Twinr now has a dedicated proactive subsystem in `src/twinr/proactive/`.
It does not try to "diagnose emotions". Instead it turns explicit sensor observations into cautious prompts such as:

- `person_returned`
- `attention_window`
- `slumped_quiet`
- `possible_fall`
- `floor_stillness`
- `showing_intent`
- `distress_possible`
- `positive_contact`

The core trigger engine is stateful and enforces per-trigger cooldowns. It consumes bounded observations from PIR, audio, and camera paths, then returns at most one suggested spoken nudge at a time.
The proactive monitor now runs as its own modular package and can be enabled behind config while the normal green/yellow button behavior stays unchanged.
Current implementation notes:

- PIR is used as the cheap wake-up signal.
- The proactive path currently uses a dedicated vision classifier prompt over still frames.
- Ambient audio can now sample the configured microphone in short bounded windows, typically the PS-Eye microphone when `TWINR_PROACTIVE_AUDIO_DEVICE` points at it.
- Background audio sampling uses a shared lock with active recording so Twinr does not open the same ALSA input twice at once.
- The hardware and realtime loops expose `handle_social_trigger(...)` so the proactive monitor can speak without pretending the user pressed the green button.

### Audio

Twinr currently uses the `reSpeaker XVF3800 4-Mic Array` as its default playback and microphone device.
The external speaker attached to the ReSpeaker is driven through that same sink.
For proactive background listening, Twinr can additionally use the `PlayStation Eye` USB microphone as a separate capture path.

Configure the audio defaults with:

```bash
cd /twinr
sudo hardware/mic/setup_audio.sh
```

The setup script also normalizes the selected playback sink and ALSA playback
controls so the ReSpeaker-attached speaker does not inherit a near-muted output
level from a previously selected sink.

To keep ReSpeaker as the main default device while also wiring the PS-Eye microphone into the proactive path, run:

```bash
cd /twinr
sudo hardware/mic/setup_audio.sh \
  --proactive-device-match Camera-B4.09.24.1 \
  --proactive-sample-ms 900 \
  --test
```

That writes the `TWINR_PROACTIVE_AUDIO_*` env keys and also runs a short direct capture smoke test against the proactive mic when configured.

### Printer

The current thermal printer is the DFRobot `DFR0503-EN`, exposed to CUPS as a Gprinter `GP-58` compatible raw printer.
This printer needs its own `9-24V` power supply for real paper output; a USB connection alone can still enumerate the device without being able to heat/feed paper.

Configure or re-create the printer queue with:

```bash
cd /twinr
sudo hardware/printer/setup_printer.sh --default --test
```

The setup script defaults to the `Thermal_GP58` queue and accepts an explicit `--device-uri` when auto-detection is not sufficient.
Both the setup smoke and the portal printer self-test only prove that a bounded print job was handed to the printer path; the operator still has to confirm the physical paper output on the device.

### Display

Twinr currently uses the `Waveshare 4.2inch e-Paper Module` with the `V2` Python driver and the standard Raspberry Pi SPI wiring.

Install the vendor driver files, persist the GPIO mapping, and run a smoke test with:

```bash
cd /twinr
sudo hardware/display/setup_display.sh
```

The current working mapping is:

- `DIN/MOSI -> GPIO10`
- `CLK -> GPIO11`
- `CS -> GPIO8`
- `DC -> GPIO25`
- `RST -> GPIO17`
- `BUSY -> GPIO24`

Run a manual test card at any time with:

```bash
cd /twinr
./.venv/bin/python hardware/display/display_test.py --env-file /twinr/.env
```

## Web dashboard

Run the local settings UI with:

```bash
cd /twinr
source .venv/bin/activate
twinr --env-file /twinr/.env --run-web
```

By default, the UI binds to `0.0.0.0:1337`, but remote browser access still
fails closed unless `TWINR_WEB_ALLOW_REMOTE=1`, `TWINR_WEB_REQUIRE_AUTH=1`,
and `TWINR_WEB_ALLOWED_HOSTS` are set in `/twinr/.env`.

When remote access is enabled without static `TWINR_WEB_USERNAME` /
`TWINR_WEB_PASSWORD` credentials, Twinr uses the managed Pi sign-in flow: the
first login is `admin / admin`, and the portal immediately requires a password
change.

## OpenAI backend

Twinr now includes an OpenAI backend slice for speech-to-text, `gpt-5.4-mini` reasoning, text-to-speech, and optional web search.

Recommended `.env` additions:

```dotenv
OPENAI_REASONING_EFFORT=medium
OPENAI_STT_MODEL=gpt-4o-mini-transcribe
OPENAI_TTS_MODEL=gpt-4o-mini-tts
OPENAI_TTS_VOICE=marin
OPENAI_TTS_FORMAT=wav
OPENAI_TTS_INSTRUCTIONS="Speak in clear, warm, natural standard German with native German pronunciation. No English accent."
OPENAI_REALTIME_MODEL=gpt-realtime-1.5
OPENAI_REALTIME_VOICE=sage
OPENAI_REALTIME_TRANSCRIPTION_MODEL=gpt-4o-mini-transcribe
OPENAI_REALTIME_LANGUAGE=de
OPENAI_REALTIME_INPUT_SAMPLE_RATE=24000
OPENAI_REALTIME_INSTRUCTIONS="Speak in clear, warm, natural standard German with native German pronunciation. No English accent."
TWINR_CONVERSATION_FOLLOW_UP_ENABLED=true
TWINR_CONVERSATION_FOLLOW_UP_TIMEOUT_S=4.0
TWINR_AUDIO_BEEP_FREQUENCY_HZ=1175
TWINR_AUDIO_BEEP_DURATION_MS=180
TWINR_AUDIO_BEEP_VOLUME=0.9
TWINR_AUDIO_BEEP_SETTLE_MS=140
OPENAI_SEND_PROJECT_HEADER=false
TWINR_OPENAI_ENABLE_WEB_SEARCH=true
TWINR_OPENAI_WEB_SEARCH_CONTEXT_SIZE=medium
TWINR_USER_DISPLAY_NAME=Thom
OPENAI_VISION_DETAIL=auto
TWINR_CAMERA_DEVICE=rpicam://0
# For a USB or UVC camera instead:
# TWINR_CAMERA_DEVICE=/dev/video0
# For the Bitcraze AI-Deck WiFi streamer instead:
# TWINR_CAMERA_DEVICE=aideck://192.168.4.1:5000
TWINR_CAMERA_WIDTH=640
TWINR_CAMERA_HEIGHT=480
TWINR_CAMERA_FRAMERATE=30
# PS Eye often works reliably with:
TWINR_CAMERA_INPUT_FORMAT=bayer_grbg8
# Optional: a stored portrait/reference image of the main user
TWINR_VISION_REFERENCE_IMAGE=/home/thh/reference-user.jpg
TWINR_PORTRAIT_MATCH_STORE_PATH=state/portrait_identities.json
TWINR_PORTRAIT_MATCH_REFERENCE_IMAGE_DIR=state/portrait_identities
TWINR_PORTRAIT_MATCH_PRIMARY_USER_ID=main_user
TWINR_PORTRAIT_MATCH_MAX_REFERENCE_IMAGES_PER_USER=6
TWINR_PORTRAIT_MATCH_IDENTITY_MARGIN=0.05
TWINR_PORTRAIT_MATCH_TEMPORAL_WINDOW_S=300.0
TWINR_PORTRAIT_MATCH_TEMPORAL_MIN_OBSERVATIONS=2
TWINR_PORTRAIT_MATCH_TEMPORAL_MAX_OBSERVATIONS=12
TWINR_PROACTIVE_ENABLED=true
TWINR_PROACTIVE_POLL_INTERVAL_S=4.0
TWINR_PROACTIVE_CAPTURE_INTERVAL_S=6.0
TWINR_PROACTIVE_MOTION_WINDOW_S=20.0
TWINR_PROACTIVE_LOW_MOTION_AFTER_S=12.0
TWINR_PROACTIVE_AUDIO_ENABLED=true
# Optional: dedicate proactive background listening to the PS-Eye mic instead of the normal input device
TWINR_PROACTIVE_AUDIO_DEVICE=plughw:CARD=CameraB409241,DEV=0
TWINR_PROACTIVE_AUDIO_SAMPLE_MS=1000
TWINR_PROACTIVE_AUDIO_DISTRESS_ENABLED=false
TWINR_PROACTIVE_VISION_REVIEW_ENABLED=true
TWINR_PROACTIVE_VISION_REVIEW_BUFFER_FRAMES=8
TWINR_PROACTIVE_VISION_REVIEW_MAX_FRAMES=4
TWINR_PROACTIVE_VISION_REVIEW_MAX_AGE_S=12.0
TWINR_PROACTIVE_VISION_REVIEW_MIN_SPACING_S=1.2
TWINR_ORCHESTRATOR_WS_URL=ws://thh-acer.local:8797/ws/orchestrator
TWINR_ORCHESTRATOR_ALLOW_INSECURE_WS=true
TWINR_VOICE_ORCHESTRATOR_ENABLED=true
TWINR_VOICE_ORCHESTRATOR_WS_URL=ws://thh-acer.local:8797/ws/orchestrator/voice
TWINR_VOICE_ORCHESTRATOR_ALLOW_INSECURE_WS=true
TWINR_VOICE_ORCHESTRATOR_REMOTE_ASR_URL=http://thh-acer.local:8797
TWINR_VOICE_ORCHESTRATOR_SHARED_SECRET=twinr-voice-gateway-20260322
```

`OPENAI_MODEL` is the central non-coding text model. Search, supervisor routing, first-word replies, conversation closure, long-term-memory text compilation, and display reserve generation inherit it unless a dedicated override is configured. Audio-specialized paths stay separate on purpose.

When the OpenAI secret is already project-scoped (`sk-proj-...`), keep `OPENAI_SEND_PROJECT_HEADER=false`. That avoids a redundant project header that can block STT/TTS while `gpt-5.4-mini` still works.

Smoke examples:

```bash
PYTHONPATH=src ./.venv/bin/python -m twinr --env-file /twinr/.env --openai-prompt "Reply with exactly OK."
PYTHONPATH=src ./.venv/bin/python -m twinr --env-file /twinr/.env --openai-prompt "What happened in the world today?" --openai-web-search
PYTHONPATH=src ./.venv/bin/python -m twinr --env-file /twinr/.env --tts-text "Hello from Twinr" --tts-output /tmp/twinr.wav
PYTHONPATH=src ./.venv/bin/python -m twinr --env-file /twinr/.env --camera-capture-output /tmp/twinr-camera.png
PYTHONPATH=src ./.venv/bin/python -m twinr --env-file /twinr/.env --vision-prompt "Bild 1 ist das Live-Kamerabild. Bild 2 ist das Referenzfoto des Nutzers. Ist es dieselbe Person? Antworte nur mit JA oder NEIN." --vision-camera-capture --vision-save-capture /tmp/twinr-camera.png --vision-image /home/thh/reference-user.jpg
PYTHONPATH=src ./.venv/bin/python -m twinr --env-file /twinr/.env --proactive-observe-once
PYTHONPATH=src ./.venv/bin/python -m twinr --env-file /twinr/.env --proactive-audio-observe-once
```

The vision path requires `ffmpeg` on the device when Twinr captures still images from V4L2. For Raspberry Pi libcamera stacks, set `TWINR_CAMERA_DEVICE=rpicam://0` (or `libcamera://0`) so Twinr uses the explicit Pi camera lane; Twinr no longer switches from a `/dev/video*` node into `rpicam-still` automatically. When `TWINR_CAMERA_DEVICE` is set to `aideck://192.168.4.1:5000`, Twinr instead reads one bounded AI-Deck WiFi frame directly, debayers raw streamer output into a normal PNG on demand, and then sends one or more images to the OpenAI Responses API in a single request. In that mode, the Twinr host itself must already be connected to the AI-Deck access point.
The active realtime and streaming loops can also trigger the camera automatically for typical visual requests such as "Schau mich mal an", "Was zeige ich dir?", or "Wie sehe ich heute aus?".
With `TWINR_PROACTIVE_ENABLED=true`, the active runtime loops also start the proactive monitor and let it issue bounded conversation starters while Twinr is idle.
With `TWINR_PROACTIVE_VISION_REVIEW_ENABLED=true`, image-driven proactive prompts are reviewed against a short buffered frame sequence before Twinr speaks. That second opinion is conservative: if the recent frames look empty or ambiguous, or if buffered review is unavailable, Twinr skips the proactive prompt instead of speaking.
With `TWINR_VOICE_ORCHESTRATOR_ENABLED=true`, the Pi keeps one live websocket stream open to the transcript-first voice gateway and leaves wake detection there. The same remote stream stays authoritative for wake, transcript commit, continuation, and follow-up closure. Twinr has no separate local wake or STT path in the live product flow.
On `/twinr`, those voice-gateway URLs must point to the development-host LAN bridge or mDNS name, not `127.0.0.1`; loopback there only points back to the Pi itself and will break live wake/reconnect.
When the current development-host `:8797` bridge is used, both the text orchestrator probe path and the live voice gateway still run over plain `ws://` transport without TLS termination. Set `TWINR_ORCHESTRATOR_ALLOW_INSECURE_WS=true` for the text `/ws/orchestrator` endpoint and `TWINR_VOICE_ORCHESTRATOR_ALLOW_INSECURE_WS=true` for `/ws/orchestrator/voice` on that attested LAN bridge; prefer `wss://` whenever a TLS terminator is available.
Remove any retired local voice-selector env from current deployments. The live runtime contract is remote-only and fails closed on legacy local-selector config.

The active runtime loops keep the same green/yellow button UX. They can inspect the camera for typical visual requests such as "Schau mich mal an", "Was zeige ich dir?", or "Wie sehe ich heute aus?".
With `TWINR_CONVERSATION_FOLLOW_UP_ENABLED=true`, Twinr emits a short beep before listening, answers, then automatically beeps and listens again for a short follow-up window so a short back-and-forth conversation works without pressing the button every turn.

Twinr exposes a provider-neutral streaming loop:

```bash
source .venv/bin/activate
twinr --env-file /twinr/.env --run-streaming-loop
```

The streaming loop keeps the same green/yellow button semantics and background reminder/automation behavior, but runs the spoken turn as `STT -> text/tool agent -> TTS`. Today it is wired through the OpenAI Responses API adapter, so the existing Twinr tool surface still works while the provider stack is being decoupled.

The streaming loop now also supports a mixed provider stack through `.env`:

- `TWINR_STT_PROVIDER=openai|deepgram`
- `TWINR_LLM_PROVIDER=openai|groq`
- `TWINR_TTS_PROVIDER=openai`

For the cheaper migration target, set:

```bash
TWINR_STT_PROVIDER=deepgram
TWINR_LLM_PROVIDER=groq
TWINR_TTS_PROVIDER=openai
DEEPGRAM_API_KEY=...
GROQ_API_KEY=...
OPENAI_API_KEY=...
```

`OpenAI` remains the support backend for search, print composition, reminder phrasing, proactive phrasing, camera inspection, and spoken TTS while `Deepgram` handles STT and `Groq` handles the main text/tool loop.

Twinr now also exposes the first websocket orchestrator slice for the planned edge/cloud architecture:

```bash
source .venv/bin/activate
twinr --env-file /twinr/.env --run-orchestrator-server
```

And a bounded text probe against that websocket service:

```bash
source .venv/bin/activate
twinr --env-file /twinr/.env --orchestrator-probe-turn "Wie wird das Wetter morgen in Schwarzenbek?"
```

The current orchestrator slice is intentionally not the default runtime yet. It provides:

- a websocket server at `TWINR_ORCHESTRATOR_WS_URL`
- a structured `ack_id` path for pre-rendered short acknowledgements
- a remote tool bridge so the specialist worker can request Pi-local tool execution over the websocket connection

New orchestrator config keys:

- `TWINR_ORCHESTRATOR_HOST`
- `TWINR_ORCHESTRATOR_PORT`
- `TWINR_ORCHESTRATOR_WS_URL`
- `TWINR_ORCHESTRATOR_SHARED_SECRET` (optional)

Latency notes:

- `TWINR_SPEECH_PAUSE_MS` controls how quickly Twinr stops listening after you stop speaking.
- `TWINR_CONVERSATION_WEB_SEARCH=auto` keeps web search available for freshness-sensitive questions without forcing search on every turn.
- The live loop now streams LLM text internally and starts speaking sentence-by-sentence instead of waiting for the full answer before playback.

## Developer bootstrap

A minimal Python package skeleton now lives in `src/twinr`.

Twinr requires Python `3.11+`. Use the repo-local `.venv` instead of relying on a machine-global `python3`.

Typical local development flow:

- Create a virtual environment
- Install the project in editable mode
- Run the unit tests
- Run the bootstrap runtime demo
- Probe the GPIO buttons on the Raspberry Pi when hardware is attached

Example commands:

```bash
python3.11 -m venv .venv
./.venv/bin/python -m pip install -e . pytest
PYTHONPATH=src ./.venv/bin/python -m unittest discover -s test -v
PYTHONPATH=src ./.venv/bin/python -m twinr --demo-transcript "Hello Twinr"
hardware/buttons/setup_buttons.sh --green 23 --yellow 22
sudo hardware/mic/setup_audio.sh
./.venv/bin/python hardware/buttons/probe_buttons.py --env-file /twinr/.env --configured --duration 15
```

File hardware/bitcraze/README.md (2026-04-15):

# bitcraze

Provision a clean Crazyradio/Crazyflie workspace for Twinr-side drone work.

## Responsibility

`hardware/bitcraze` owns:
- install the Crazyradio USB udev rules needed for non-root access
- stage pinned Crazyradio 2.0 firmware assets for compatibility and recovery
- create an isolated Python workspace under `/twinr/bitcraze`
- install the pinned Bitcraze Python packages into that workspace
- probe the connected Bitcraze USB device and confirm whether it is ready for `cflib`

`hardware/bitcraze` does **not** own:
- Twinr runtime orchestration
- drone behavior policy
- direct source-of-truth code changes in `/twinr` without first updating `/home/thh/twinr`

## Compatibility note

The current official `cflib` and `cfclient` releases still expect the classic
Crazyradio PA USB identity (`1915:7777`). If a Crazyradio 2.0 is attached in
its UF2/native state (`35f0:bad2`), this setup path stages both firmware
variants but defaults to the PA-emulation UF2 for immediate Python-library
compatibility.

## Key files

| File | Purpose |
|---|---|
| [setup_bitcraze.sh](./setup_bitcraze.sh) | Install USB access rules, stage firmware assets, create `/twinr/bitcraze`, optionally flash a compatible UF2, and install the pinned Bitcraze Python workspace |
| [probe_crazyradio.py](./probe_crazyradio.py) | Inspect connected Bitcraze USB devices, classify the current mode, and validate the local workspace/`cflib` access path |
| [prepare_olimex_jtag.sh](./prepare_olimex_jtag.sh) | Check or prepare host prerequisites for AI-Deck GAP8 JTAG recovery with the Olimex ARM-USB-TINY-H bundle, including optional `openocd`/`docker` installation and runtime-user group prep |
| [CRAZYFLIE_RECOVERY_RUNBOOK.md](./CRAZYFLIE_RECOVERY_RUNBOOK.md) | Authoritative Crazyflie 2.x recovery path, decision order, and incident learnings from the proven brick/recovery case |
| [FIRMWARE_RELEASE_LANES.md](./FIRMWARE_RELEASE_LANES.md) | Fail-closed dev/bench/operator/recovery firmware release process for the on-device failsafe |
| [probe_multiranger.py](./probe_multiranger.py) | Connect to the Crazyflie, read the current deck flags, and sample Multi-ranger directions plus supporting Flow/Z-ranger presence for immediate post-install acceptance |
| [probe_deck_bus.py](./probe_deck_bus.py) | Run one bounded non-rotor deck-bus probe that power-cycles the STM32/deck rail by default, then captures firmware `deck.*`, refreshed memory TOC evidence, and startup console lines for the proven `I2C1` deck-bus failure mode |
| [on_device_failsafe.py](./on_device_failsafe.py) | Host-side Appchannel adapter that proves the firmware app is loaded, sends heartbeat/config packets plus one bounded hover intent, and records the v4 returned mission/failsafe status packets including bounded debug truth |
| [hover_primitive.py](./hover_primitive.py) | Internal helper module for deterministic hover pre-arm params, SITL/replay hover primitives, and shared takeoff/landing contracts; live hardware no longer uses it as the takeoff/hover control owner |
| [local_navigation.py](./local_navigation.py) | Pure host-side local-navigation policy that converts one bounded Multi-ranger clearance snapshot into one deterministic short-range translation or hover-anchor-only decision |
| [capture_runtime_telemetry.py](./capture_runtime_telemetry.py) | Thin wrapper that starts the shared runtime telemetry module on one Crazyflie session and emits one bounded JSON snapshot for the daemon/operator path |
| [replay_hover_trace.py](./replay_hover_trace.py) | Replay one stored hover report and optional phase trace through the real bounded hover primitive so unsafe live runs become deterministic regressions before the next flight |
| [run_hover_test.py](./run_hover_test.py) | Run one bounded takeoff-hover-land flight test; on real hardware it now sends one bounded hover intent to `twinrFs` and only observes/reports mission status, while SITL still uses the host primitive lane |
| [run_local_inspect_mission.py](./run_local_inspect_mission.py) | Run one bounded `takeoff -> optional local translation -> still capture -> land` inspect mission; live hardware is currently blocked until the mission is migrated onto the same on-device `twinrFs` control lane |
| [build_on_device_failsafe.sh](./build_on_device_failsafe.sh) | Build the Crazyflie STM32 on-device failsafe app from a pinned Bitcraze firmware checkout and emit a build attestation |
| [build_patched_crazyflie_firmware.sh](./build_patched_crazyflie_firmware.sh) | Build one patched official Crazyflie STM32 firmware image from a pinned clean checkout plus explicit repo-local patch files, then emit `cf2.bin`, `cf2.elf`, and a build manifest outside the temporary worktree |
| [patches/crazyflie_firmware_zranger2_invalid_status_fail_closed.patch](./patches/crazyflie_firmware_zranger2_invalid_status_fail_closed.patch) | Repo-local Crazyflie firmware fix for the `zranger2` driver so invalid VL53L1 readings surface as explicit invalid range instead of collapsing to `0 mm` |
| [firmware_release_policy.py](./firmware_release_policy.py) | Shared lane/attestation policy for build, promotion, flash, and recovery interlocks |
| [promote_on_device_failsafe_release.py](./promote_on_device_failsafe_release.py) | Promote one attested custom firmware artifact into the bench or operator release lane |
| [flash_on_device_failsafe.py](./flash_on_device_failsafe.py) | Flash a lane-authorized STM32 artifact through `cfloader` and verify the new `twinrFs` firmware app over the normal radio link |
| [twinr_on_device_failsafe/](./twinr_on_device_failsafe) | Crazyflie app-layer hover/failsafe controller in C that owns bounded takeoff/hover/landing plus local safe-land and obstacle-repel behavior without host tick control |

## Usage

```bash
sudo ./hardware/bitcraze/setup_bitcraze.sh --workspace /twinr/bitcraze --runtime-user thh
python3 hardware/bitcraze/probe_crazyradio.py --workspace /twinr/bitcraze
python3 hardware/bitcraze/probe_crazyradio.py --workspace /twinr/bitcraze --json
sudo ./hardware/bitcraze/prepare_olimex_jtag.sh --workspace /twinr/bitcraze --install-apt --ensure-user-groups
/twinr/bitcraze/.venv/bin/python hardware/bitcraze/probe_multiranger.py --workspace /twinr/bitcraze --require-deck multiranger --json
bash hardware/bitcraze/build_patched_crazyflie_firmware.sh --firmware-root /tmp/crazyflie-firmware --expected-firmware-revision 2025.12.1
/twinr/bitcraze/.venv/bin/python hardware/bitcraze/probe_deck_bus.py --workspace /twinr/bitcraze --json
bash hardware/bitcraze/build_on_device_failsafe.sh --firmware-root /tmp/crazyflie-firmware --expected-firmware-revision 2025.12.1
bash hardware/bitcraze/build_on_device_failsafe.sh --firmware-root /tmp/crazyflie-firmware --expected-firmware-revision 2025.12.1 --patch hardware/bitcraze/patches/crazyflie_firmware_zranger2_invalid_status_fail_closed.patch
python3 hardware/bitcraze/promote_on_device_failsafe_release.py --lane bench --release-id twinr-failsafe-bench-2026-04-11-r1 --approved-by thh --reason "bench validation passed" --validation-evidence test:test_bitcraze_flash_on_device_failsafe.py
/twinr/bitcraze/.venv/bin/python hardware/bitcraze/flash_on_device_failsafe.py --lane dev --device-role dev --attestation hardware/bitcraze/twinr_on_device_failsafe/build/twinr_on_device_failsafe.build-attestation.json --json
/twinr/bitcraze/.venv/bin/python hardware/bitcraze/run_hover_test.py --workspace /twinr/bitcraze --json
python3 hardware/bitcraze/run_local_inspect_mission.py --repo-root /home/thh/twinr --workspace /twinr/bitcraze --bitcraze-python /twinr/bitcraze/.venv/bin/python --artifact-root /tmp/drone-artifacts --image-name inspect.png --json
python3 hardware/bitcraze/capture_runtime_telemetry.py --workspace /twinr/bitcraze --profile operator --json
python3 hardware/bitcraze/replay_hover_trace.py --report-json /tmp/hover-report.json --trace-file /tmp/hover-trace.jsonl --json
```

For operator recovery after a bad Crazyflie flash, use
[CRAZYFLIE_RECOVERY_RUNBOOK.md](./CRAZYFLIE_RECOVERY_RUNBOOK.md). The important
default is now explicit: if the `nRF` bootloader is alive, prefer the official
coordinated Bitcraze release ZIP over `Crazyradio` before escalating to direct
`SWD`/`JTAG` work.

There is now one proven narrower `nRF` exception to keep in mind. On the
current `Crazyflie 2.1 + AI deck + Flow v2 + Multi-ranger` stack, we proved one
state where:
- the `STM32` side was already correct
- the `Crazyradio` dongle was already fixed
- the `nRF` received valid packets
- but the radio path still returned no usable ACKs

For that exact state, the recovery that restored the normal radio path was:
- keep the official `nRF` bootloader/MBS/UICR intact
- rebuild the official `crazyflie2-nrf-firmware` tag `2025.12` with `BLE=0`
- flash only the `nRF` app image at `0x0001B000` over `SWD`

That exact sequence is documented in
[CRAZYFLIE_RECOVERY_RUNBOOK.md](./CRAZYFLIE_RECOVERY_RUNBOOK.md) under
`Verified nRF Radio ACK Failure Mode`.

There is now also one proven `STM32`-side exception that can look deceptively
similar from the host:

- raw `Crazyradio` ACKs are healthy
- `scan_interfaces()` still returns `radio://0/80/2M`
- but `protocol_version` stays `-1` and the platform handshake never completes

In that case the remaining blocker may be the `STM32` app hanging on the
`I2C1` deck bus before `commInit()`, not the radio path. The verified
reproduction in `2025.12.1` was an unbounded deck-bus unlock loop in
`i2cdrvdevUnlockBus()` while SDA stayed low. The repo-local bounded fail-closed
patch is:

- `hardware/bitcraze/patches/crazyflie_firmware_i2c1_boot_hang_fail_closed.patch`

The full recovery sequence and proof path are recorded in
`hardware/bitcraze/CRAZYFLIE_RECOVERY_RUNBOOK.md` under
`Verified STM32 Deck-Bus Boot Hang Failure Mode`.

The new non-rotor follow-up probe for that exact failure mode is
[probe_deck_bus.py](./probe_deck_bus.py). It does not spin motors. It captures:
- firmware `deck.*` flags after a clean `fully_connected` state
- explicit `cf.mem.refresh()` evidence from the memory TOC
- bounded firmware console output after boot

By default it also performs one bounded `STM32`/deck power-cycle first. That
is intentional: Bitcraze deck discovery is startup-only, so a hot-reconfigured
deck stack can otherwise look falsely missing even when the software path is
healthy.

That is the correct software-side truth surface before any physical deck-stack
isolation. If those three sources all show the deck stack missing, the
remaining narrowing step is physical: remove or reseat one deck or interconnect
at a time and rerun the same bounded probe until the missing evidence comes
back.

For deck bring-up and post-recovery acceptance, the runbook now also captures a
second important rule: do not treat deck LEDs or deck power as proof of deck
detection. The authoritative order is:
- firmware `deck.*` params
- firmware memory TOC after `cf.mem.refresh()`
- one clean bounded probe such as [probe_multiranger.py](./probe_multiranger.py)

If those disagree, trust the firmware-side evidence over visual cues and follow
the deck-enumeration diagnostic order in
[CRAZYFLIE_RECOVERY_RUNBOOK.md](./CRAZYFLIE_RECOVERY_RUNBOOK.md) before
concluding that the deck stack is electrically missing.

Related operator rule: after any physical deck-stack change, either fully
power-cycle the Crazyflie or use the default `probe_deck_bus.py` path that
power-cycles the `STM32` and decks before probing. Do not trust `deck.*` from
the already-running session after hot reattachment.

There is now one narrower Z-ranger software failure mode to keep in mind during
hover acceptance. The upstream `zranger2` driver used to ignore the VL53L1
`RangeStatus` field and wrote invalid readings straight into `range.zrange` as
`0 mm`. Under real takeoff vibration and bus activity that can look like a hard
floor lock even though the correct interpretation is "invalid reading". The
repo-local patch above converts those invalid readings into the normal invalid
sentinel path instead of silent zero-height truth.

Once the AI-Deck WiFi streamer is flashed, Twinr can treat it as a normal
still camera by setting `TWINR_CAMERA_DEVICE=aideck://192.168.4.1:5000`. On
hosts that already sit on the AI-Deck AP, the standard Twinr camera capture
and vision-request entrypoints read one bounded frame directly from the deck
stream. On single-WiFi hosts with `nmcli`, Twinr now performs one bounded
handover to the AI-Deck AP for the capture and then restores the previous WiFi
connection before the upstream OpenAI/runtime path continues.

When the Pi receives a DHCP lease on `192.168.4.x` and TCP connect to
`192.168.4.1:5000` succeeds but no bytes arrive, the remaining blocker is the
AI-Deck streamer itself rather than Twinr's network handover. In that state,
power-cycle the drone and prefer the Bitcraze station-mode setup over AP mode
for longer-running Twinr vision experiments.

For the incoming Olimex ARM-USB-TINY-H bundle, Twinr now has a dedicated host
prep script that can stage the JTAG recovery workspace, install missing
`openocd`/`docker` prerequisites, and ensure the runtime user is in the
expected serial/USB groups before the hardware is attached.

For the incoming Multi-ranger deck, Twinr now has a dedicated bounded probe
that checks `deck.bcMultiranger`, `deck.bcFlow2`, `deck.bcZRanger2`, and
samples `front/back/left/right/up/down` range data over the normal radio URI.
That gives us an immediate acceptance test as soon as the deck is mounted. Use
that probe together with the raw firmware `deck.*` values when diagnosing
strange deck states; one stale or host-disturbed read is not enough evidence to
declare the whole stack dead.

For the first live flight primitive, Twinr now also ships one bounded hover
worker that only does `takeoff -> hover -> land` after explicit deck and
battery preflight. On real hardware that worker is now mission-intent only: it
submits one bounded hover mission over Appchannel to `twinrFs`, then observes
and reports the resulting on-device state machine. The host no longer owns
per-tick takeoff/hover corrections over radio on the real aircraft. When the
Multi-ranger deck is present, the same preflight samples one short clearance
snapshot and blocks takeoff if front/back/left/right/up obstacles are already
too close for a safe hover envelope. Before the mission starts, the worker now
also applies and verifies a deterministic hover-time firmware setup:
- `stabilizer.estimator=2`
- `stabilizer.controller=1`
- `motion.disable=0`
- `kalman.resetEstimation` pulse and verification back to `0`

Takeoff is then gated behind a bounded Kalman-settling check that waits for
stable `kalman.varPX/PY/PZ`, quiet roll/pitch, usable `motion.squal`, and a
valid downward `range.zrange` reading. On the real aircraft, the subsequent
staged mission now runs on-device inside `twinrFs`. On the host, the old
stateful hover primitive remains only as the SITL/replay/shared-contract lane.

That split is deliberate. The real aircraft now proves its staged
`takeoff -> hover -> landing` contract next to the Crazyflie EKF/controller
path on the STM32. The host no longer tries to infer or correct those phases
over the radio link in real time.

The April 2026 on-device refactor also made the STM32 lane structurally
explicit instead of keeping one growing C file. `twinrFs` is now split into
protocol, telemetry, mission-control, failsafe-control, and state-machine
modules. The next SOC slice then pulled the remaining control arithmetic out of
mission orchestration as well: `twinrFs` now has dedicated pure-C
`vertical_control` and `disturbance_control` helpers for bounded hover-thrust
estimation, takeoff progress classification, and lateral disturbance
classification. The host stays limited to mission intent plus observation.

The April 2026 control-ownership change now makes one stricter split between
simulator and real aircraft. CrazySim still starts its bounded hover lane with
the host-side primitive because the simulator-owned height lane is the thing
under test there. Real hardware no longer does that. The bounded takeoff /
hover / landing mission state machine now lives in `twinrFs` on the STM32 and
receives only one bounded hover intent from the host. That keeps the critical
decisions next to the firmware EKF/controller path instead of on a slower
host-radio loop.

For live-flight forensics, the worker now records the on-device `twinrFs`
status surface rather than pretending to own the control loop. That gives each
hardware run one explicit state/reason trail from the firmware mission owner
instead of a second competing host-side bootstrap story.

The STM32 takeoff truth is now stricter as well. `twinrFs` no longer treats one
single good `range.zrange`/`motion.squal` sample as enough to hand off into
hover. It keeps short consecutive counters for range freshness, range rise,
flow liveness, and attitude quiet, exposes those counters in the `twinrFs`
log group, and times out with an explicit on-device reason when one of those
proofs never converges. The same log group now also exports the vertical
progress class plus filtered-battery and disturbance severity/recoverability
signals so a failed live hover can be classified from the firmware owner
without rebuilding controller state in Python.

That on-device truth lane now also classifies the next two real post-qualify
failure states instead of leaving them implicit in the trace:

- `truth_stale`: hover had already qualified, then range/flow truth went stale
  for the bounded on-device window
- `state_flapping`: takeoff-truth inputs regressed repeatedly before handoff
  and never converged into one stable qualified-hover state
- `ceiling_without_progress`: the vertical helper hit its bounded takeoff
  ceiling long enough without proving real range rise
- `disturbance_nonrecoverable`: the lateral disturbance helper kept observing a
  non-recoverable XY bias long enough that local hover recovery was no longer
  accepted
- `takeoff_overshoot`: the vertical helper saw strong bounded overshoot above
  the micro-liftoff target instead of a controlled hover handoff

For local regression, Twinr now also has one firmware-near harness for those
pure on-device helpers under
[../../test/fixtures/twinrfs_control_harness.c](../../test/fixtures/twinrfs_control_harness.c)
plus [../../test/test_bitcraze_twinrfs_control_harness.py](../../test/test_bitcraze_twinrfs_control_harness.py).
That harness compiles the extracted C modules directly and proves the vertical
handoff/ceiling-abort and lateral recover/abort contracts before the next
hardware flash.

The host preflight no longer trusts one arbitrary `pm.state` / supervisor
packet either. It now captures one bounded preflight status window, treats the
latest sample as the authoritative start state, and records any `power.state`,
`can_arm`, `can_fly`, or `is_armed` flapping explicitly as a blocked-preflight
reason. That removes the old single-sample randomness from repeated host-side
hover reruns.

There is one important grounded-start exception now documented in code as well
as in the worker behavior. Bitcraze documents the PMW3901 optical-flow sensor
as only tracking motion from about `80 mm`, and Bitcraze engineering guidance
for takeoff issues suggests ignoring flow below roughly `0.1 m`. The hover
worker therefore does not hard-block takeoff on `motion.squal` or lateral
Kalman variance while the downward range still says the craft is sitting in
that blind near-ground band. In that state it only requires the vertical range,
vertical variance, and bench-stable roll/pitch gates before allowing the
bounded takeoff primitive to lift into the flow sensor's usable range.

The worker also writes bounded in-flight telemetry for attitude, position and
velocity estimates, gyro motion, optical-flow quality, downward and directional
range sensing, battery sag, radio RSSI, thrust, and supervisor safety flags so
a successful run includes real stability evidence rather than only a pass/fail
outcome. The persisted artifact now also includes the verified pre-arm param
snapshot, the estimator-settle summary, and the primitive outcome in addition
to the in-air telemetry summary. That telemetry now comes from the canonical
shared runtime lane in `src/twinr/hardware/crazyflie_telemetry.py` rather than
from per-worker collectors, so hover, local inspect, and daemon state all read
the same bounded profile-driven runtime surface. `run_local_inspect_mission.py`
now also consumes the same explicit `runtime_mode` contract as
`run_hover_test.py` instead of carrying a separate implicit hardware-only path.
The Bitcraze scripts still run through `/twinr/bitcraze/.venv`, not the
repo-local `.venv`.

The landing side of the primitive is now staged as well instead of dropping
straight from hover to stop-setpoints: it first descends to a low near-ground
floor, briefly settles there, then switches to a slower touchdown stage,
briefly holds zero-height setpoints, and only then allows motor cutoff after a
deterministic landing-complete signal. Landing completion is now intentionally
joint: fresh downward `range.zrange` at or below the current `5 cm` cutoff and
a fresh supervisor `is flying = false` report must both be present for the
required confirmation window. This is deliberate: Bitcraze's
`send_stop_setpoint()` is a hard motor stop that can otherwise make the drone
fall, while range-only ground contact can still lag the firmware's internal
flight state enough to produce a short re-hop. Once airborne, the hover worker
therefore keeps driving the landing path until that joint ground truth arrives
or the bounded timeout forces a loud `touchdown_not_confirmed` outcome.
The explicit CrazySim `sitl` lane now keeps that hardware contract intact for
real flights while using one equally explicit simulator contract: touchdown may
complete from the simulator-owned height lane without waiting for
hardware-style supervisor grounded telemetry that stays high under repeated
`hover(z=0)` setpoints in SITL.

For timeout/debug forensics it also accepts `--trace-file` and streams phase
breadcrumbs such as `sync_connect`, `pre_arm_params`, `estimator_settle`,
`telemetry_stop`, `sync_disconnect`, `report_build`, and `json_emit` to a
JSONL file so teardown hangs still leave durable evidence. The persisted
telemetry summary uses the inferred airborne window instead of mixing in
pre-takeoff estimator-settle samples, and it drops invalid range sentinels
like `0` and `32766` so drift and clearance numbers better reflect the actual
hover. It now also distinguishes the structured cases `no_samples` versus
`raw_samples_missing_airborne_window` so a live run with captured telemetry but
missing airborne qualification no longer looks like a total telemetry outage.
That summary now also keeps two separate truth surfaces for optical flow:
airborne-window `flow_observed` and raw-run `raw_flow_observed`. This matters
when a failed takeoff never enters the airborne window even though `motion.squal`
was already nonzero in the raw telemetry. In the same report, the telemetry
summary now classifies the takeoff lateral lane separately through
`takeoff_lateral_classification` so we can distinguish:

- nonzero on-device lateral commands during `mission_takeoff`
- unexpected lateral command sources during `mission_takeoff`
- estimator-bias evidence without any commanded takeoff laterals
- fully raw takeoff drift with zero on-device lateral command and zero
  disturbance estimate

Hover acceptance is fail-closed as well: runs are marked unstable when
the measured altitude rises far above the requested hover height or when
battery sag under load drops below the bounded safety floor, even if the
telemetry stream itself stayed alive.

For host-loss safety, the hover path now has a second layer below Python: a
Crazyflie app-layer failsafe in [twinr_on_device_failsafe/](./twinr_on_device_failsafe)
runs directly on the STM32 in C with a `20 ms` local control loop. The host
only sends bounded Appchannel heartbeats plus thresholds through
[on_device_failsafe.py](./on_device_failsafe.py). If that heartbeat stops,
the on-device app can still locally brake, repel away from nearby obstacles,
descend, and only disarm after touchdown confirmation. This is the correct
language/runtime split for performance and determinism: the real emergency path
stays on the aircraft, Python only configures and observes it.

The important April 2026 takeoff lesson is that the on-device app must not arm
lateral `front/back/left/right` clearance just because the supervisor or
estimator momentarily claims flight while the craft is still on the floor.
`twinrFs` now treats valid downward `range.zrange` as the authoritative liftoff
proof and only arms lateral clearance once that measured height really exceeds
the near-ground floor. Pre-liftoff it still honors `up` clearance, but a failed
takeoff must now end in one quiet landed state instead of looping through
`failsafe_brake -> failsafe_descend -> touchdown_confirm -> monitoring` on the
ground.

There is now one host-side rule on top of that firmware change:
`run_hover_test.py` and `run_local_inspect_mission.py` start `twinrFs` with
lateral clearance explicitly disarmed and only arm it after the host primitive
has confirmed a real takeoff. The host preflight now follows the same contract:
while the craft is still below the shared active-takeoff height, it requires
`up` clearance but does not hard-block on side-facing `front/back/left/right`
ToF readings that can still see floor geometry near the ground. Once the shared
active height is reached, the normal lateral clearance gate becomes strict.

Hover acceptance is stricter now as well. A run is marked unstable not only on
overshoot or battery sag, but also when it never reaches the commanded
target-height gate or when the in-air telemetry shows excessive drift,
excessive roll/pitch, or excessive horizontal speed. The primitive now has an
explicit `stabilize -> hover_hold` split: it first waits for a bounded stable
window after takeoff, and if that live guard keeps seeing too much height
error, drift, speed, or attitude, it aborts early into landing instead of
continuing an obviously bad hover for seconds. A brief hop or eiernder ascent
no longer counts as a successful bounded hover.

That current hover lane should also be named precisely: it is
`flow_relative_hover`, not true absolute `position_hold`. The host sends
`send_hover_setpoint(vx=0, vy=0, yawrate=0, z=...)`, and the Crazyflie holds
height plus body-frame zero velocity using relative flow/dead-reckoning. That
is enough for bounded hover acceptance and short local inspect maneuvers, but
it is not the end architecture for "stand still at one exact point". Real
stationary position hold remains a separate positioning track that needs an
absolute pose source or a future visual-anchor lane.

Twinr now adds one bounded host-side outer-loop on top of that `flow_relative_hover`
lane: [crazyflie_flow_anchor.py](../../src/twinr/hardware/crazyflie_flow_anchor.py)
turns fresh `stateEstimate.{x,y,z,vx,vy}`, `stabilizer.yaw`, and downward range
into small corrective body-frame velocity targets plus a trusted-height signal.
This does not replace the Crazyflie inner controller. It only gives the host a
single, bounded way to resist lateral drift and to reject raw `range.zrange`
surface switches or ToF outliers as fake hover altitude.

Build and flash that firmware path before relying on bounded hover acceptance:

```bash
bash hardware/bitcraze/build_on_device_failsafe.sh --firmware-root /tmp/crazyflie-firmware --expected-firmware-revision 2025.12.1
/twinr/bitcraze/.venv/bin/python hardware/bitcraze/flash_on_device_failsafe.py --lane dev --device-role dev --attestation hardware/bitcraze/twinr_on_device_failsafe/build/twinr_on_device_failsafe.build-attestation.json
```

The generated build output stays under
`hardware/bitcraze/twinr_on_device_failsafe/build/`, but that tree is a local
firmware workspace only. It is not treated as authoritative source for Pi repo
mirroring and is intentionally excluded from the `/home/thh/twinr -> /twinr`
sync contract.

When extending the `twinrFs` param surface, keep Bitcraze's `CMD_GET_ITEM_V2`
TOC size limit in mind. For params and logs, `group + name + 2` must stay at
or below `26` bytes. Exceeding that budget can assert in `param_logic.c`
during boot and later fail the normal-start check through
`cfAssertNormalStartTest()`.

The post-flash helper reconnects over the normal radio URI and proves the app
through `twinrFs.protocolVersion`, `twinrFs.enable`, `twinrFs.state`, and
`twinrFs.reason`. The hover worker's default `--on-device-failsafe-mode required`
now blocks takeoff unless that proof is present.

If the `STM32` app hash is already correct but the post-flash reconnect still
dies with missing ACKs or `Too many packets lost`, debug the `nRF` radio path
before reflashing the same `STM32` image again. In the proven April 2026
incident, the remaining blocker after the `STM32` fix was the `nRF` ACK-return
path, and the decisive recovery was an official `2025.12` `nRF` rebuild with
`BLE=0`.

On top of that hover/failsafe lane, Twinr now has a first bounded local-inspect
mission worker in [run_local_inspect_mission.py](./run_local_inspect_mission.py).
It deliberately does not create a second flight stack. Instead it reuses the
same pre-arm params, estimator-settle gate, shared runtime telemetry, and
on-device failsafe proof as the hover worker, then adds only three
mission-specific layers:
- host-side bounded local-navigation planning in [local_navigation.py](./local_navigation.py)
- one short body-frame translation via the explicit stateful primitive in [hover_primitive.py](./hover_primitive.py)
- one bounded still capture through Twinr's normal camera abstraction before deterministic landing

`run_local_inspect_mission.py` now reuses the same live stabilize/hover guard
as `run_hover_test.py`, so local inspect can no longer skip directly from
takeoff to translation/capture on a visibly unstable hover state.

That same shared runtime telemetry lane also has one thin operator/daemon entry
point in [capture_runtime_telemetry.py](./capture_runtime_telemetry.py). It
starts one explicit profile such as `operator`, `hover_acceptance`,
`inspect_local_zone`, or `forensics`, then emits one bounded JSON snapshot that
the daemon can expose through `GET /state` without reimplementing cflib log
ownership itself.

Hover debugging now also has a sim-first lane. First capture the unsafe live
hover report and optional phase trace, then replay it through
[replay_hover_trace.py](./replay_hover_trace.py) so the same bounded hover
primitive, guard logic, and landing contract run deterministically without
touching live hardware. Only after that replay path proves the fix should the
same bug return to live flight.

`replay_hover_trace.py` now replays the real hardware start contract too:
- `--runtime-mode hardware` exercises the bounded raw-thrust/manual `micro_liftoff` and requires fresh `range.zrange` plus nonzero flow before hover-mode handoff
- `--runtime-mode sitl` keeps using the simulator-owned `stateEstimate.z` ground-distance contract and does not require flow quality

For closed-loop SITL beyond raw replay, Twinr now owns a strict CrazySim
adapter in `src/twinr/hardware/crazysim_adapter.py`. Twinr does not vendor
CrazySim or guess its workspace layout; the adapter accepts only an
operator-managed checkout with the expected CrazySim single-agent launch script
and fails closed otherwise.

On top of that baseline SITL lane, Twinr now also has a deterministic CrazySim
scenario runner in [run_hover_sim_scenarios.py](./run_hover_sim_scenarios.py).
It does not invent a second hover stack. Instead it:
- captures one real CrazySim hover baseline through [run_hover_sim.py](./run_hover_sim.py) or reuses one stored hover report
- mutates that baseline into bounded scenario artifacts such as `drift_bias`, `flow_dropout`, `zrange_outlier`, `attitude_spike`, `wall_proximity`, and transient recovery disturbances
- replays each scenario through the same bounded hover primitive and shared stability evaluation used by the live worker

That gives Twinr one repeatable sim-first regression lane for exactly the
classes of failures that were dangerous on real hardware: uncontrolled lateral
motion, untrusted flow, fake downward-range altitude jumps, close obstacle
approach, and bounded recovery after a transient shove. The recovery lane does
not pretend to prove full plant-physics restabilization. It proves the current
software contract instead: Twinr must issue the expected opposing correction
and return to bounded hover output within the declared recovery window. Use it
before the next live hover iteration:

```bash
./.venv/bin/python hardware/bitcraze/run_hover_sim_scenarios.py \
  --crazysim-root /tmp/crazysim \
  --backend mujoco \
  --python-bin /tmp/crazysim-cflib-venv/bin/python \
  --json \
  -- --height-m 0.25 --hover-duration-s 1.0
```

Or reuse a stored hover report without relaunching CrazySim:

```bash
./.venv/bin/python hardware/bitcraze/run_hover_sim_scenarios.py \
  --baseline-report-json /tmp/hover-report.json \
  --scenario transient_forward_drift_recovery \
  --scenario persistent_forward_drift_abort \
  --scenario transient_left_drift_recovery \
  --scenario transient_height_drop_recovery \
  --json
```

The transient recovery scenarios currently cover:
- `transient_forward_drift_recovery`: a bounded forward drift impulse must trigger a bounded backward command and then settle
- `persistent_forward_drift_abort`: the same forward axis, but sustained long enough that the hover guard must block on bounded instability instead of recovering
- `transient_left_drift_recovery`: a bounded lateral drift impulse must trigger the opposing lateral command and then settle
- `transient_height_drop_recovery`: a bounded height underestimate must raise the commanded hover height briefly and then settle

The scenario lane now separates two contracts explicitly:
- `recover`: the disturbance must produce the expected opposing command and must not drive the stability guard into `blocked`
- `abort`: the disturbance must trip the stability guard on declared failure codes instead of silently drifting into a bad post-flight grade

To make this a single acceptance lane instead of two separate manual steps,
Twinr now also has [run_hover_acceptance_gate.py](./run_hover_acceptance_gate.py).
It gates hover/guard work on both:
- one or more stored JSONL/report replay cases through the shared replay lane
- one deterministic CrazySim scenario suite against either a fresh or stored baseline
- one CrazySim physical disturbance suite, either fresh from MuJoCo or loaded from a stored suite JSON
- and, for fresh MuJoCo runs, repeated nominal baselines that must all pass the same touchdown contract before the gate can mark the lane `live_flight_eligible=true`

The gate fails closed if either side fails:

```bash
./.venv/bin/python hardware/bitcraze/run_hover_acceptance_gate.py \
  --replay-case "/tmp/unsafe-live-hover.json||hardware" \
  --crazysim-root /tmp/crazysim \
  --backend mujoco \
  --python-bin /tmp/crazysim-cflib-venv/bin/python \
  --json \
  -- --height-m 0.25 --hover-duration-s 1.0
```

For stored-only validation without relaunching CrazySim:

```bash
./.venv/bin/python hardware/bitcraze/run_hover_acceptance_gate.py \
  --replay-case "/tmp/unsafe-live-hover.json||hardware" \
  --baseline-report-json /tmp/crazysim-baseline-hover.json \
  --physical-suite-json /tmp/crazysim-physical-suite.json \
  --scenario baseline_nominal \
  --scenario persistent_forward_drift_abort \
  --scenario drift_bias \
  --scenario flow_dropout \
  --scenario attitude_spike \
  --scenario wall_proximity \
  --json
```

The acceptance gate is now explicit about its policy:
- replay proves that real unsafe flights stay reproducible as regressions
- the adversarial SITL suite proves guard behavior against telemetry/state mutations
- the physical disturbance suite proves recover-vs-abort behavior against live MuJoCo force/torque disturbances
- fresh nominal repeatability proves that CrazySim readiness and touchdown semantics are deterministic enough to trust the rest of the fresh gate

MuJoCo acceptance now runs headless by default. That is deliberate: the viewer
lane is useful for manual operator inspection, but repeated fresh regression
and disturbance suites proved less stable there because the GUI/GLFW startup
path can fail before the same hover stack even starts. Use
`--visualize --display :0` only for manual debugging, not as the default proof
lane.

If any of those three lanes fail, the gate stays closed and the next live hover should not happen yet.
Stored-only gate runs remain useful for regression work, but they intentionally do not mark the stack `live_flight_eligible=true`.

For recovery-specific acceptance on top of one fresh CrazySim baseline:

```bash
./.venv/bin/python hardware/bitcraze/run_hover_sim_scenarios.py \
  --crazysim-root /tmp/crazysim \
  --backend mujoco \
  --python-bin /tmp/crazysim-cflib-venv/bin/python \
  --scenario baseline_nominal \
  --scenario transient_forward_drift_recovery \
  --scenario persistent_forward_drift_abort \
  --scenario transient_left_drift_recovery \
  --scenario transient_height_drop_recovery \
  --json
```

For real MuJoCo plant disturbances instead of replay-only mutations, Twinr also
has [run_hover_sim_disturbances.py](./run_hover_sim_disturbances.py). That lane
injects explicit force/torque pulses into the live CrazySim plant and then
replays the resulting hover artifact through the same recover-vs-abort
contracts. Use it when the question is no longer "would the replay logic ask
for the right correction?" but "does the current hover stack still recover or
abort correctly when the simulated aircraft is actually shoved off balance?"

```bash
./.venv/bin/python hardware/bitcraze/run_hover_sim_disturbances.py \
  --crazysim-root /tmp/crazysim \
  --backend mujoco \
  --python-bin /tmp/crazysim-cflib-venv/bin/python \
  --json \
  -- --height-m 0.25 --hover-duration-s 1.0
```

The physical suite currently separates two categories on the same live plant:
- `physical_*_recovery`: bounded impulses that must trigger the expected opposing command and then resettle without a blocked hover guard
- `physical_*_abort`: stronger or sustained disturbances that must fail closed through the declared hover guard or takeoff abort path instead of drifting into an ambiguous outcome

Current default physical cases:
- `physical_forward_impulse_recovery`
- `physical_left_impulse_recovery`
- `physical_height_drop_recovery`
- `physical_persistent_forward_abort`
- `physical_roll_torque_abort`

The current local-navigation policy is intentionally conservative:
- it reads one short-range Multi-ranger clearance envelope
- it either chooses one small bounded `forward/left/right/back` translation or stays at the current hover anchor
- it prefers the lane with the largest bounded travel budget after enforcing the post-move clearance contract
- it never attempts open-ended navigation, mapping, or free flight

The custom firmware path itself is now split out into
[FIRMWARE_RELEASE_LANES.md](./FIRMWARE_RELEASE_LANES.md). That document is the
authoritative path for:
- pinned source builds
- bench promotion
- operator promotion
- strict separation between custom firmware and official recovery

Run the Bitcraze probes with `/twinr/bitcraze/.venv` rather than the repo-local
`.venv`. The Bitcraze stack currently wants a newer `numpy` line than Twinr, so
the isolated Bitcraze workspace remains the supported runtime path.

## Generated workspace

The setup script creates a reproducible runtime workspace under
`/twinr/bitcraze` containing:
- `.venv/` with pinned `cflib` and `cfclient`
- `firmware/` with staged UF2 assets and any captured `CURRENT.UF2` backups
- `README.md` with the exact pinned versions and the local probe commands

## See also

- [hardware/README.md](../README.md)
- [hardware/AGENTS.md](../AGENTS.md)

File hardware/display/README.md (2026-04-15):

# display

Pi-side setup and smoke-test scripts for Twinr's display backends.

## Responsibility

`display` owns:
- persist HDMI Wayland/framebuffer or Waveshare env settings
- install and patch the Waveshare vendor driver when the legacy e-paper path is selected
- run bounded display smoke commands outside the main runtime

`display` does **not** own:
- runtime rendering logic in `src/twinr/display`
- main Twinr CLI orchestration
- unrelated GPIO, audio, or printer setup

## Key files

| File | Purpose |
|---|---|
| [setup_display.sh](./setup_display.sh) | Configure the active display backend and env wiring |
| [vendor_patch.py](./vendor_patch.py) | Download and harden the generated Waveshare vendor package |
| [display_test.py](./display_test.py) | Render one-shot test pattern on the configured backend |
| [run_display_loop.py](./run_display_loop.py) | Run the standalone status loop |
| [run_visual_qc.py](./run_visual_qc.py) | Capture the visible HDMI scene set, diff it, and persist a report-backed artifact bundle |
| [probe_busy_path.py](./probe_busy_path.py) | Instrument one bounded BUSY/RST/SPI full-refresh probe on the Pi for the Waveshare path |

## Usage

```bash
sudo ./hardware/display/setup_display.sh --env-file .env
sudo ./hardware/display/setup_display.sh --env-file .env --driver hdmi_wayland --layout debug_log --runtime-trace true
sudo ./hardware/display/setup_display.sh --env-file .env --driver hdmi_fbdev
python3 hardware/display/display_test.py --env-file .env
python3 hardware/display/run_display_loop.py --env-file .env --duration 30
python3 hardware/display/run_visual_qc.py --env-file .env
python3 hardware/display/probe_busy_path.py --env-file .env --steady-renders 6
```

`setup_display.sh` now defaults to `hdmi_wayland`. It probes `/dev/fb0` for the
active mode, auto-detects the active Wayland socket when possible, writes the
Wayland/runtime env needed for the visible fullscreen Twinr surface, and for
HDMI also sets the senior-facing `default` layout with runtime tracing
disabled. For HDMI it also installs `fonts-noto-color-emoji`, because the
right-hand Unicode emoji reserve depends on the system
`NotoColorEmoji.ttf` font. Pass `--layout debug_log --runtime-trace true` when operators
explicitly want the richer live-diagnostics surface on the panel. HDMI setup
also removes the old Waveshare GPIO/SPI env keys so the runtime stops touching
the retired e-paper path.

`display_test.py` forwards bounded telemetry to stdout. On `hdmi_wayland` it
prints the resolved Wayland socket/runtime dir and mode; on `hdmi_fbdev` it
prints the resolved framebuffer path and mode; on Waveshare it still prints the
legacy driver and BUSY GPIO.

`run_visual_qc.py` is the screenshot-backed HDMI acceptance path. It:
- drives the public face-expression and presentation controllers through a bounded scene set
- captures the visible Wayland surface with `grim`
- computes transition diff heatmaps and changed-pixel metrics
- writes a durable report under `artifacts/reports/report/<RPT...>/` when the
  repo report tool is usable, otherwise under
  `artifacts/reports/display_visual_qc/<RUN_ID>/`

The current scene set covers `idle_home`, `face_react`, `presentation_mid`,
`presentation_focused`, and `restored_home`, so Twinr's senior-facing screen
can be validated with concrete before/mid/focused/after evidence instead of
manual screenshots.

For the optional HDMI news ticker, enable it in `.env`. The runtime display
loop then reads from Twinr's active world-intelligence subscriptions and
fetches/cache headlines asynchronously:

```dotenv
TWINR_DISPLAY_NEWS_TICKER_ENABLED=true
TWINR_DISPLAY_NEWS_TICKER_STORE_PATH=artifacts/stores/ops/display_news_ticker.json
TWINR_DISPLAY_NEWS_TICKER_REFRESH_INTERVAL_S=900
TWINR_DISPLAY_NEWS_TICKER_ROTATION_INTERVAL_S=12
TWINR_DISPLAY_NEWS_TICKER_MAX_ITEMS=12
TWINR_DISPLAY_NEWS_TICKER_TIMEOUT_S=4
```

The ticker bar only appears on HDMI default surfaces, hides during fullscreen
presentations, and uses cached fallback text when a fresh feed download is not
yet available.

Older Pi `.env` files may still contain `TWINR_DISPLAY_NEWS_TICKER_FEED_URLS`.
Twinr imports that legacy list one-way into the shared world-intelligence
subscription pool when the pool is still empty, then keeps reading from the
shared pool instead of from a separate static ticker list.

For manual HDMI face-trigger validation, write one short-lived cue artifact
into the configured cue path and let the running display loop pick it up on the
next cycle. Example:

```bash
PYTHONPATH=src python3 - <<'PY'
from twinr.agent.base_agent import TwinrConfig
from twinr.display import (
    DisplayFaceBrowStyle,
    DisplayFaceExpressionController,
    DisplayFaceGazeDirection,
    DisplayFaceMouthStyle,
)

config = TwinrConfig.from_env(".env")
controller = DisplayFaceExpressionController.from_config(config, default_source="camera_surface")
cue = controller.show(
    gaze=DisplayFaceGazeDirection.UP_RIGHT,
    brows=DisplayFaceBrowStyle.RAISED,
    mouth=DisplayFaceMouthStyle.SMILE,
    hold_seconds=5.0,
)
print(controller.store.path)
print(cue)
PY
```

For the full screenshot-backed QC bundle:

```bash
python3 hardware/display/run_visual_qc.py --env-file .env --keep-workdir
```

That command prints the generated `report_id`, the report markdown path, the
imported report assets, and per-transition diff metrics.

For manual HDMI presentation validation, use the producer-facing presentation
controller instead of hand-writing raw JSON. Example:

```bash
PYTHONPATH=src python3 - <<'PY'
from twinr.agent.base_agent import TwinrConfig
from twinr.display import DisplayPresentationController

config = TwinrConfig.from_env(".env")
controller = DisplayPresentationController.from_config(config, default_source="operator")
cue = controller.show_rich_card(
    title="Family call",
    subtitle="Marta is waiting",
    body_lines=("Press the green button to answer.",),
    accent="warm",
    hold_seconds=15.0,
)
print(controller.store.path)
print(cue)
PY
```

For fullscreen image validation:

```bash
PYTHONPATH=src python3 - <<'PY'
from twinr.agent.base_agent import TwinrConfig
from twinr.display import DisplayPresentationController

config = TwinrConfig.from_env(".env")
controller = DisplayPresentationController.from_config(config, default_source="operator")
cue = controller.show_image(
    image_path="/tmp/family_photo.png",
    title="New photo",
    subtitle="Delivered just now",
    body_lines=("The card should morph to fullscreen.",),
    accent="success",
    hold_seconds=20.0,
)
print(controller.store.path)
print(cue)
PY
```

For prioritized multi-card scene validation:

```bash
PYTHONPATH=src python3 - <<'PY'
from twinr.agent.base_agent import TwinrConfig
from twinr.display import DisplayPresentationCardCue, DisplayPresentationController

config = TwinrConfig.from_env(".env")
controller = DisplayPresentationController.from_config(config, default_source="operator")
cue = controller.show_scene(
    cards=(
        DisplayPresentationCardCue(key="summary", title="Daily summary", priority=20, accent="info"),
        DisplayPresentationCardCue(
            key="family_photo",
            kind="image",
            title="Family photo",
            image_path="/tmp/family_photo.png",
            priority=90,
            accent="warm",
            face_emotion="happy",
        ),
    ),
    hold_seconds=20.0,
)
print(controller.store.path)
print(cue)
PY
```

`probe_busy_path.py` remains Waveshare-only: it instruments vendor `ReadBusy()`,
GPIO writes for `RST`/`PWR`, SPI command/bulk-write phases, and bounded supply
snapshots so Pi debugging can prove whether a hang occurred during `init()`,
`display()/TurnOnDisplay()`, or the recovery `Clear()` path.

For live runtime debugging, enable:

```dotenv
TWINR_DISPLAY_RUNTIME_TRACE_ENABLED=true
```

That keeps Twinr on the supervisor path but emits bounded `display_trace=...`,
`display_trace_gpio=...`, and `display_trace_supply=...` lines into the
service journal with phase, caller, last command, previous status, GPIO, and
supply context. Use the standalone probe when you need an exclusive panel
session; use the runtime trace when you need to catch the first stall inside
the normal supervisor-managed Twinr loop. On `hdmi_wayland`, the same flag also
adds a compact `display_trace=render_path ...` summary plus a structured
`display_render_trace` ops event for each real status render, so Pi probes can
separate snapshot pickup, `show_status()`, `show_image()`, `processEvents()`,
and the backend's internal present boundary without patching ad-hoc print
statements into the companion.

## See also

- [Top-level hardware README](../README.md)
- [Runtime display package](../../src/twinr/display/README.md)

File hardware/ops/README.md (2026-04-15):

# hardware/ops

Pi-side operating-system service definitions plus leading-repo mirror helpers,
plus the development-host units that expose the remote-only voice gateway
contract to the Pi.

Legacy note: the helper-Pi camera and servo proxies are no longer kept inside
the active `hardware/ops` tree. Historical recovery artifacts now live under
`__legacy__/hardware/ops/`. Current Twinr runtime wiring is single-Pi; the
canonical config loader rejects the retired helper-Pi camera and servo envs
instead of treating them as supported operating modes.

## Responsibility

`hardware/ops` owns:
- the authoritative systemd unit that keeps the productive Twinr runtime running on the Pi
- the dedicated systemd unit that keeps the remote-memory watchdog alive across runtime-supervisor restarts
- OS-level launch wiring for background checks and runtime processes that must survive shell logout or crashes
- the development-host bounded drone daemon that exposes Twinr's mission-level inspection contract behind manual-arm and preflight gates
- the development-host orchestrator server unit that keeps the host-side `remote_asr` websocket endpoint and embedded `/v1/transcribe` surface alive
- the development-host LAN bridge that exposes a stable `:8797` websocket port to the Pi while forwarding byte-for-byte into that host-side orchestrator endpoint
- the Pi-side bootstrap entrypoint for self-coding Codex prerequisites
- the Pi-side operator script that fail-closes the OpenAI env contract before isolated provider probes
- the development-host operator script that joins the current local release, the Pi's persisted `current_release_manifest.json`, and a live checksum drift probe into one release-alignment report
- the development-host operator script that diagnoses the public ChonkyDB endpoint against the dedicated backend service and only restarts the backend when that backend is the proven failing layer
- the development-host operator script that stabilizes the dedicated Twinr ChonkyDB host when shared-host system units, user-session units, or non-Twinr workers directly pointed at the dedicated backend reclaim CPU/I/O from it
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

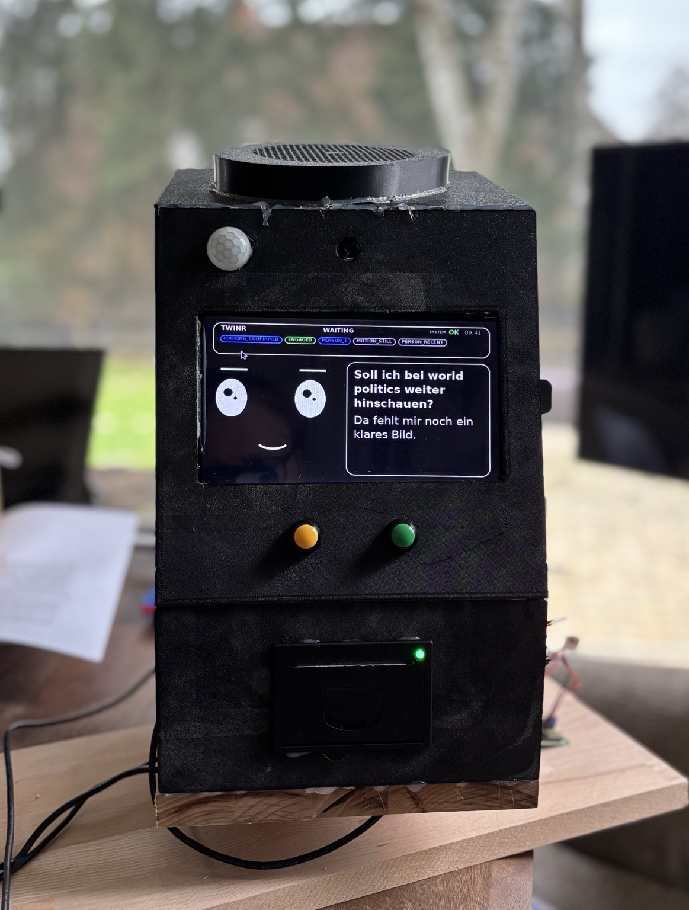
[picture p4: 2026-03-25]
twinr-prototype.jpeg

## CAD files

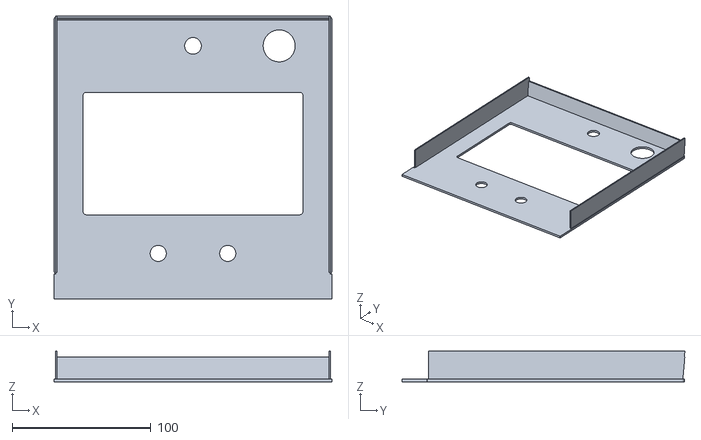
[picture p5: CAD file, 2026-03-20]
3dprint/main_panel.stl
200.0 x 203.4 x 22.0

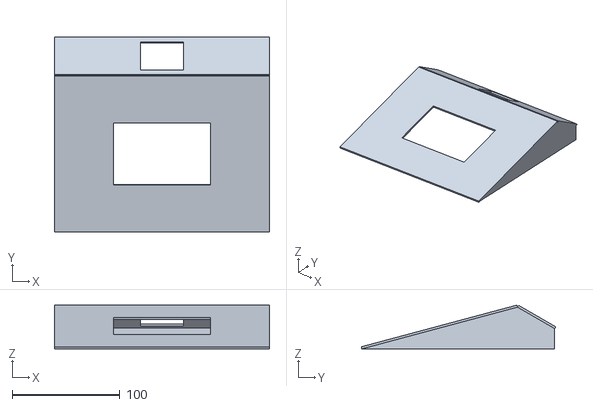
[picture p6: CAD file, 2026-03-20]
3dprint/top_panel.stl
200.0 x 181.0 x 40.8

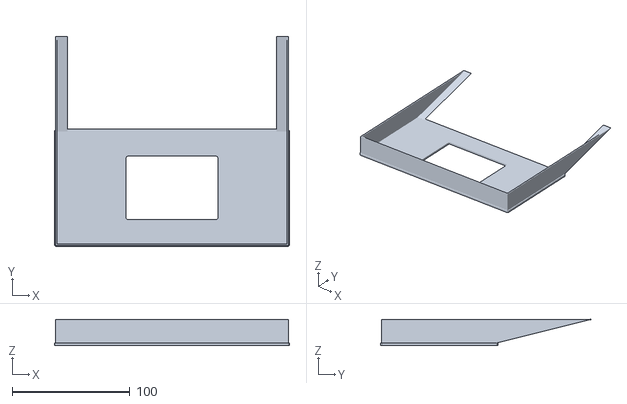
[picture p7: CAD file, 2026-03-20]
3dprint/thermal_printer.stl
200.0 x 179.0 x 22.2

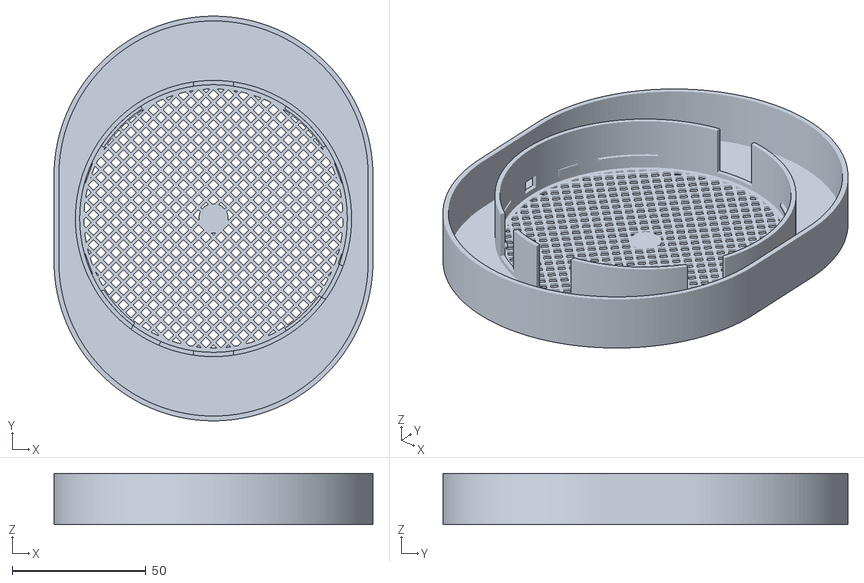
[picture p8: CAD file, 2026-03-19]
3dprint/respeaker.stl
119.1 x 151.1 x 19.2

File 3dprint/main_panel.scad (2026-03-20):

//
// Sloped screen/front panel with full-width bottom glue lip
// and upper angled lip
//
// - centered screen cutout: 158 x 88 mm
// - screen keepout behind the panel, so other parts are not too close
// - Raspberry Pi AI Camera cutout
// - PIR cutout: 23 mm
// - 2x Same Sky pushbutton cutouts: 11.6 mm
// - full-width bottom glue lip
// - upper angled lip with 1 mm inset
// - side tray walls as wedges so they close into the upper lip
//
// Export:
//   part = "panel";   // STL
//   part = "preview"; // with dummy geometry
//

part = "panel";   // "panel" | "preview"

// =========================
// MAIN SIZE
// =========================

// visible main panel
panel_w = 200.0;
panel_h = 185.0;

// bottom glue lip: SAME WIDTH as panel
glue_lip_w = panel_w;
glue_lip_h = 18.0;

plate_t = 2.0;
outer_corner_r = 2.0;

// tray walls / "Wanne"
rim_inset = 1.0;
rim_t     = 1.2;
rim_depth = 20.0;

// upper angled lip
top_lip_t         = rim_t;
top_lip_depth     = 16.0;
top_lip_angle_deg = 5.0;   // if you meant relative to the existing 60°/30° section, try 25.0

// =========================
// SCREEN + KEEPOUT
// =========================

// visible cutout
screen_w = 158.0;
screen_h = 88.0;
screen_r = 2.0;
screen_cx = 0.0;
screen_cy = -6.0;

// larger real module behind the opening
screen_keepout_w = 172.0;
screen_keepout_h = 104.0;

// clearances from keepout to neighboring cutouts
upper_clear = 14.0;
lower_clear = 14.0;

// =========================
// CAMERA / PIR / BUTTONS
// =========================

// Raspberry Pi AI Camera
// default: round lens hole only
use_camera_rect = false;
camera_hole_d = 12.0;
camera_rect_w = 14.0;
camera_rect_h = 14.0;
camera_rect_r = 1.0;

// PIR
pir_hole_d = 23.0;

// Buttons
button_hole_d = 11.6;
button_spacing = 50.0;  // center-to-center

// layout logic
upper_row_cy = screen_cy + screen_keepout_h/2 + upper_clear + max(camera_hole_d/2, pir_hole_d/2);
button_cy    = screen_cy - screen_keepout_h/2 - lower_clear - button_hole_d/2;

// positions
camera_cx = 0.0;
camera_cy = upper_row_cy;

pir_cx = 62.0;
pir_cy = upper_row_cy;

button1_cx = -button_spacing/2;
button2_cx =  button_spacing/2;

// =========================
// PREVIEW DUMMIES
// =========================

dummy_screen_t = 4.0;
dummy_camera_d = 11.9;
dummy_pir_d    = 23.0;
dummy_button_d = 11.6;

show_keepout_preview = true;

// =========================
// DERIVED VALUES
// =========================

main_bottom_y = -panel_h/2;
main_top_y    =  panel_h/2;

y_bottom_in   = main_bottom_y + rim_inset;
y_top_in      = main_top_y    - rim_inset;

top_lip_rise = top_lip_depth * tan(top_lip_angle_deg);

y_lip_front_center = y_top_in - top_lip_t/2;
y_lip_back_center  = y_lip_front_center + top_lip_rise;

y_lip_back_high = y_lip_back_center + top_lip_t/2;

// basic sanity
assert(glue_lip_w == panel_w, "Bottom glue lip must have the same width as the panel.");
assert(camera_cy + max(camera_hole_d/2, camera_rect_h/2) < main_top_y - 4, "Camera too close to top edge.");
assert(pir_cy + pir_hole_d/2 < main_top_y - 4, "PIR too close to top edge.");
assert(button_cy - button_hole_d/2 > main_bottom_y + 4, "Buttons too close to bottom edge.");

// =========================
// 2D HELPERS
// =========================

module rounded_rect_2d(w, h, r) {
    rr = min(r, min(w, h) / 2);
    if (rr <= 0) {
        square([w, h], center = true);
    } else {
        hull() {
            for (x = [-w/2 + rr, w/2 - rr])
                for (y = [-h/2 + rr, h/2 - rr])
                    translate([x, y]) circle(r = rr, $fn = 32);
        }
    }
}

module panel_outline_2d() {
    union() {
        // main panel
        rounded_rect_2d(panel_w, panel_h, outer_corner_r);

        // full-width bottom glue lip
        translate([0, main_bottom_y - glue_lip_h/2 + 0.01])
            square([glue_lip_w, glue_lip_h + 0.02], center = true);
    }
}

module screen_cutout_2d() {
    translate([screen_cx, screen_cy])
        rounded_rect_2d(screen_w, screen_h, screen_r);
}

module camera_cutout_2d() {
    translate([camera_cx, camera_cy]) {
        if (use_camera_rect) {
            rounded_rect_2d(camera_rect_w, camera_rect_h, camera_rect_r);
        } else {
            circle(d = camera_hole_d, $fn = 64);
        }
    }
}

module pir_cutout_2d() {
    translate([pir_cx, pir_cy])
        circle(d = pir_hole_d, $fn = 72);
}

module button_cutouts_2d() {
    translate([button1_cx, button_cy])
        circle(d = button_hole_d, $fn = 64);

    translate([button2_cx, button_cy])
        circle(d = button_hole_d, $fn = 64);
}

// =========================
// FRONT PLATE
// =========================

module front_plate() {
    linear_extrude(height = plate_t, convexity = 10)
        difference() {
            panel_outline_2d();
            screen_cutout_2d();
            camera_cutout_2d();
            pir_cutout_2d();
            button_cutouts_2d();
        }
}

// =========================
// SIDE WALLS AS WEDGES
// =========================
//
// They start at the main panel area only
// and rise toward the upper angled lip,
// so there is no side gap.
//

module side_wall_wedge(x_outer) {
    eps = 0.02;

    front_h = y_top_in - y_bottom_in;
    back_h  = y_lip_back_high - y_bottom_in;

    hull() {
        // front strip
        translate([
            x_outer + rim_t/2,
            (y_bottom_in + y_top_in)/2,
            plate_t + eps/2
        ])
            cube([rim_t, front_h, eps], center = true);

        // rear strip, taller to meet upper lip
        translate([
            x_outer + rim_t/2,
            (y_bottom_in + y_lip_back_high)/2,
            plate_t + rim_depth - eps/2
        ])
            cube([rim_t, back_h, eps], center = true);
    }
}

module left_wall() {
    side_wall_wedge(-panel_w/2 + rim_inset);
}

module right_wall() {
    side_wall_wedge(panel_w/2 - rim_inset - rim_t);
}

// =========================
// UPPER ANGLED LIP
// =========================
//
// 1 mm inset from the left/right edges,
// extends backward and rises slightly.
//

module top_angled_lip() {
    span_x = panel_w - 2*rim_inset;
    eps = 0.02;

    hull() {
        // front strip at top inner edge
        translate([0, y_lip_front_center, plate_t + eps/2])
            cube([span_x, top_lip_t, eps], center = true);

        // rear strip, slightly higher
        translate([0, y_lip_back_center, plate_t + top_lip_depth - eps/2])
            cube([span_x, top_lip_t, eps], center = true);
    }
}

// =========================
// PANEL ASSEMBLY
// =========================

module panel() {
    union() {
        front_plate();
        left_wall();
        right_wall();
        top_angled_lip();
    }
}

// =========================
// PREVIEW
// =========================

module dummy_screen() {
    color([0.1, 0.1, 0.1, 0.45])
        translate([screen_cx, screen_cy, plate_t])
            linear_extrude(height = dummy_screen_t, convexity = 10)
                rounded_rect_2d(screen_w - 1.0, screen_h - 1.0, 1.5);
}

module dummy_screen_keepout() {
    if (show_keepout_preview) {
        color([0.8, 0.2, 0.2, 0.20])
            translate([screen_cx, screen_cy, plate_t + 0.2])
                linear_extrude(height = 8.0, convexity = 10)
                    rounded_rect_2d(screen_keepout_w, screen_keepout_h, 2.0);
    }
}

module dummy_camera() {
    color([0.2, 0.5, 0.8, 0.45])
        translate([camera_cx, camera_cy, plate_t])
            cylinder(h = 8.0, d = dummy_camera_d, $fn = 48);
}

module dummy_pir() {
    color([0.85, 0.85, 0.85, 0.5])
        translate([pir_cx, pir_cy, plate_t])
            cylinder(h = 10.0, d = dummy_pir_d, $fn = 72);
}

module dummy_buttons() {
    color([0.2, 0.2, 0.2, 0.5]) {
        translate([button1_cx, button_cy, plate_t])
            cylinder(h = 10.0, d = dummy_button_d, $fn = 48);

        translate([button2_cx, button_cy, plate_t])
            cylinder(h = 10.0, d = dummy_button_d, $fn = 48);
    }
}

module preview() {
    panel();
    dummy_screen();
    dummy_screen_keepout();
    dummy_camera();
    dummy_pir();
    dummy_buttons();
}

// =========================
// OUTPUT
// =========================

if (part == "preview") {
    preview();
} else {
    panel();
}

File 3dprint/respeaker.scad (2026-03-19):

//
// ReSpeaker XVF3800 + XIAO ESP32S3
// OVAL TOP CAP WITH HIDDEN CABLE CHANNEL
//
// Konzept:
// - nur Oberteil / Haube
// - innen: runder Mesh-Bereich über dem ReSpeaker
// - außen: geschlossener ovaler Kabelkanal
// - außen keine Öffnungen
// - unten komplett offen: Kabel werden unten aus dem Oval nach unten abgeführt
// - innere Kreiswand bekommt Reliefs für USB-C / Audio / Speaker / Buttons
// - keine Schrauben
//
// Druck:
// - mit Top-Seite / Mesh nach unten aufs Bett
// - kein Support
//
// Export:
//   part = "cap";
//   part = "preview";
//
// FIRST-PASS:
// - board_d ist bewusst parametrierbar
// - erst Test-Fit drucken
//

part = "cap";   // "cap" | "preview"

// =========================
// HAUPTPARAMETER
// =========================

// ReSpeaker PCB - First pass
board_d = 99.0;
board_t = 4.0;

// Passung am PCB
fit_clear = 0.45;   // radialer Abstand PCB -> Innenwand
grip_depth = 0.45;  // leichte Klemmung über Grip-Ribs
grip_w = 8.0;
grip_h = 2.8;

// Wandstärken - bewusst schlanker als vorher
device_wall_t = 1.60;   // innere Kreiswand um das Gerät
outer_wall_t  = 1.80;   // äußere Ovalwand
face_t        = 1.00;   // Top-Dicke
top_gap       = 1.20;   // Abstand Mesh-Unterseite -> PCB-Oberseite
comp_clear    = 13.00;  // Tiefe nach unten für XIAO, USB-C-Stecker, etc.

// Ovaler Außenkanal
side_channel_w = 8.00;   // seitliche Kanalbreite links/rechts
tb_extra       = 16.00;  // zusätzliche Ausdehnung oben/unten

// Gesamthöhe
cap_h = face_t + top_gap + board_t + comp_clear;

// =========================
// MESH
// =========================

mesh_pitch        = 5.60;
mesh_bar_w        = 1.20;
mesh_center_hub_r = 5.50;
mesh_angle_a      = 45;
mesh_angle_b      = -45;
mesh_rim_w        = 2.00;

// =========================
// BOARD-SITZ / HALTUNG
// =========================

// Board liegt auf 4 Segmentauflagen
shelf_inset  = 1.10;
shelf_t      = 0.90;
shelf_arc    = 24;
shelf_angles = [45, 135, 225, 315];

// zusätzliche Grip-Ribs gegen Wackeln
grip_z0      = face_t + top_gap + 0.70;
grip_angles  = [20, 160, 200, 340];

// =========================
// EDGE-RELIEFS IN DER INNEREN KREISWAND
// =========================

// Winkel:
// 0° = rechts
// 90° = oben
// 180° = links
// 270° = unten

xiao_usb_angle = 90;
xmos_usb_angle = 270;
audio_angle    = 240;
speaker_angle  = 332;
mute_angle     = 0;
reset_angle    = 180;

// tangentiale Breiten der Reliefs
xiao_usb_w = 15.0;
xmos_usb_w = 15.0;
audio_w    = 12.0;
speaker_w  = 14.0;
button_w   =  5.8;

// =========================
// ABGELEITETE MASSE
// =========================

pcb_top_z    = face_t + top_gap;
pcb_bottom_z = pcb_top_z + board_t;

device_inner_r = board_d/2 + fit_clear;
device_outer_r = device_inner_r + device_wall_t;

// Außenoval = "Kapsel" / Stadium
outer_capsule_r    = device_outer_r + side_channel_w;
outer_capsule_offy = tb_extra;

// Mesh nur im inneren Kreis
mesh_outer_r = device_outer_r - 1.20;
mesh_field_r = mesh_outer_r - mesh_rim_w;

// Relief-Zonen
port_z0    = pcb_top_z + 0.40;
button_z0  = pcb_top_z + 0.80;
button_z1  = button_z0 + 4.50;

inner_relief_depth = device_wall_t + 6.0;

// =========================
// 2D-HELFER
// =========================

module capsule2d(r, offy) {
    hull() {
        translate([0,  offy]) circle(r = r, $fn = 180);
        translate([0, -offy]) circle(r = r, $fn = 180);
    }
}

module stripe_field_2d(r, pitch, bar_w, angle_deg) {
    intersection() {
        circle(r = r, $fn = 220);
        union() {
            for (y = [-2*r : pitch : 2*r]) {
                translate([0, y])
                    rotate(angle_deg)
                        square([4*r, bar_w], center = true);
            }
        }
    }
}

module top_face_2d() {
    union() {
        // alles außerhalb des Mesh-Kreises ist geschlossen
        difference() {
            capsule2d(outer_capsule_r, outer_capsule_offy);
            circle(r = mesh_outer_r, $fn = 220);
        }

        // kleiner Innenring am Mesh-Rand für saubere Anbindung
        difference() {
            circle(r = mesh_outer_r, $fn = 220);
            circle(r = mesh_field_r, $fn = 220);
        }

        // verbundenes Diamond-Mesh
        stripe_field_2d(mesh_field_r + 0.02, mesh_pitch, mesh_bar_w, mesh_angle_a);
        stripe_field_2d(mesh_field_r + 0.02, mesh_pitch, mesh_bar_w, mesh_angle_b);

        // stabiler Kern
        circle(r = mesh_center_hub_r, $fn = 100);
    }
}

// =========================
// 3D-HELFER
// =========================

module top_face() {
    linear_extrude(height = face_t, convexity = 10)
        top_face_2d();
}

module inner_device_wall() {
    linear_extrude(height = cap_h, convexity = 10)
        difference() {
            circle(r = device_outer_r, $fn = 240);
            circle(r = device_inner_r, $fn = 240);
        }
}

module outer_oval_wall() {
    linear_extrude(height = cap_h, convexity = 10)
        difference() {
            capsule2d(outer_capsule_r, outer_capsule_offy);
            capsule2d(outer_capsule_r - outer_wall_t, outer_capsule_offy);
        }
}

module ring_arc_segment(r_in, r_out, z0, h, center_angle, arc_angle) {
    rotate([0, 0, center_angle - arc_angle/2])
        translate([0, 0, z0])
            rotate_extrude(angle = arc_angle, convexity = 10, $fn = 96)
                translate([r_in, 0])
                    square([r_out - r_in, h], center = false);
}

module support_shelves() {
    for (a = shelf_angles) {
        ring_arc_segment(
            device_inner_r - shelf_inset,
            device_inner_r,
            pcb_bottom_z - shelf_t,
            shelf_t,
            a,
            shelf_arc
        );
    }
}

module grip_rib(angle_deg) {
    rotate([0, 0, angle_deg])
        translate([device_inner_r - grip_depth/2, 0, grip_z0 + grip_h/2])
            cube([grip_depth, grip_w, grip_h], center = true);
}

module grip_ribs() {
    for (a = grip_angles) {
        grip_rib(a);
    }
}

module wall_window(angle_deg, center_r, tangential_w, z0, z1, depth) {
    rotate([0, 0, angle_deg])
        translate([center_r, 0, (z0 + z1)/2])
            cube([depth, tangential_w, z1 - z0], center = true);
}

module inner_reliefs() {
    // beide USB-C Ports
    wall_window(
        xiao_usb_angle,
        device_outer_r - device_wall_t/2,
        xiao_usb_w,
        port_z0,
        cap_h + 0.10,
        inner_relief_depth
    );

    wall_window(
        xmos_usb_angle,
        device_outer_r - device_wall_t/2,
        xmos_usb_w,
        port_z0,
        cap_h + 0.10,
        inner_relief_depth
    );

    // AUX + Speaker JST - nur innere Reliefs, außen bleibt geschlossen
    wall_window(
        audio_angle,
        device_outer_r - device_wall_t/2,
        audio_w,
        port_z0,
        cap_h + 0.10,
        inner_relief_depth
    );

    wall_window(
        speaker_angle,
        device_outer_r - device_wall_t/2,
        speaker_w,
        port_z0,
        cap_h + 0.10,
        inner_relief_depth
    );

    // Mute / Reset
    wall_window(
        mute_angle,
        device_outer_r - device_wall_t/2,
        button_w,
        button_z0,
        button_z1,
        inner_relief_depth
    );

    wall_window(
        reset_angle,
        device_outer_r - device_wall_t/2,
        button_w,
        button_z0,
        button_z1,
        inner_relief_depth
    );
}

module cap() {
    difference() {
        union() {
            top_face();
            inner_device_wall();
            outer_oval_wall();
            support_shelves();
            grip_ribs();
        }

        // nur die innere Kreiswand wird geöffnet
        inner_reliefs();
    }
}

// =========================
// PREVIEW
// =========================

module dummy_board() {
    color([0.10, 0.60, 0.20, 0.35])
        translate([0, 0, pcb_top_z])
            cylinder(h = board_t, d = board_d, $fn = 240);
}

module preview() {
    cap();
    dummy_board();
}

// =========================
// OUTPUT
// =========================

if (part == "preview") {
    preview();
} else {
    cap();
}

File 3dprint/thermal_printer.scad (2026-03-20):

//
// Frontplatte 200 x 100 mm für DFRobot Embedded Thermal Printer V2.0
// MODIFIZIERTE VERSION:
// - Seitenwände bleiben keilförmig
// - die obere schräge Ebene ist NICHT mehr vollflächig
// - stattdessen nur noch zwei schräge Randstege à 10 mm
// - mittlerer Bereich oben bleibt offen
// - Steigung standardmäßig als 15 % statt 15°
// - mittiger Printer-Cutout
// - front-face-down druckbar
//

part = "plate";   // "plate" | "preview"

// =========================
// HAUPTPARAMETER
// =========================

panel_w = 200.0;
panel_h = 100.0;

plate_t = 2.2;
outer_corner_r = 2.0;

rim_inset = 1.0;
rim_t = 1.2;
rim_depth = 20.0;

// Obere Schräge:
// Standard = 15 % Steigung über rim_depth
use_slope_percent = true;
top_mount_slope_percent = 400.0;

// Nur falls du doch Winkel statt Prozent willst:
top_mount_angle_from_front = 15.0;

top_wall_t = rim_t;

// neue schräge Randstege
top_rail_w = 10.0;   // jeweils 1 cm breit

// DFRobot Printer Cutout
printer_install_w = 77.2;
printer_install_h = 53.2;
printer_open_extra_w = 0.8;
printer_open_extra_h = 0.8;

printer_open_w = printer_install_w + printer_open_extra_w;
printer_open_h = printer_install_h + printer_open_extra_h;
printer_cutout_r = 1.5;

// Dummy preview
dummy_body_w = 77.2;
dummy_body_h = 53.2;
dummy_body_d = 42.0;

dummy_bezel_w = 82.1;
dummy_bezel_h = 58.1;
dummy_bezel_t = 2.0;

// =========================
// ABGELEITETE WERTE
// =========================

top_mount_rise = use_slope_percent
    ? rim_depth * top_mount_slope_percent / 100
    : rim_depth * tan(90 - top_mount_angle_from_front);

y_bottom    = -panel_h/2 + rim_inset;
y_top_inner =  panel_h/2 - rim_inset;

// obere schräge Stege
y_front_center = y_top_inner - top_wall_t/2;
y_back_center  = y_front_center + top_mount_rise;

y_front_low  = y_front_center - top_wall_t/2;
y_front_high = y_front_center + top_wall_t/2;
y_back_low   = y_back_center  - top_wall_t/2;
y_back_high  = y_back_center  + top_wall_t/2;

// X-Positionen der Seitenwände
x_left_outer  = -panel_w/2 + rim_inset;
x_right_outer =  panel_w/2 - rim_inset;

// X-Positionen der oberen Randstege
x_left_rail_center  = x_left_outer + top_rail_w/2;
x_right_rail_center = x_right_outer - top_rail_w/2;

// =========================
// 2D-HELFER
// =========================

module rounded_rect_2d(w, h, r) {
    rr = min(r, min(w, h) / 2);
    if (rr <= 0) {
        square([w, h], center = true);
    } else {
        hull() {
            for (x = [-w/2 + rr, w/2 - rr])
                for (y = [-h/2 + rr, h/2 - rr])
                    translate([x, y]) circle(r = rr, $fn = 32);
        }
    }
}

module printer_cutout_2d() {
    rounded_rect_2d(printer_open_w, printer_open_h, printer_cutout_r);
}

// =========================
// FRONTPLATTE
// =========================

module front_plate() {
    linear_extrude(height = plate_t, convexity = 10)
        difference() {
            rounded_rect_2d(panel_w, panel_h, outer_corner_r);
            printer_cutout_2d();
        }
}

// =========================
// SEITENWÄNDE ALS KEILE
// =========================

module side_wall_wedge(x_outer) {
    eps = 0.02;

    front_h = y_top_inner - y_bottom;
    back_h  = y_back_high - y_bottom;

    hull() {
        // vorderer Rechteck-Streifen
        translate([
            x_outer + rim_t/2,
            (y_bottom + y_top_inner)/2,
            plate_t + eps/2
        ])
            cube([rim_t, front_h, eps], center = true);

        // hinterer höherer Rechteck-Streifen
        translate([
            x_outer + rim_t/2,
            (y_bottom + y_back_high)/2,
            plate_t + rim_depth - eps/2
        ])
            cube([rim_t, back_h, eps], center = true);
    }
}

module left_wall() {
    side_wall_wedge(x_left_outer);
}

module right_wall() {
    side_wall_wedge(x_right_outer - rim_t);
}

// =========================
// BODENWAND
// =========================

module bottom_wall() {
    translate([
        -panel_w/2 + rim_inset + rim_t,
        y_bottom,
        plate_t
    ])
        cube([
            panel_w - 2*(rim_inset + rim_t),
            rim_t,
            rim_depth
        ], center = false);
}

// =========================
// OBERE SCHRÄGE RANDSTEGE
// =========================
//
// Keine Vollfläche mehr.
// Nur noch links und rechts je ein 10-mm-Steg.
//

module top_sloped_rail(x_center, rail_w) {
    eps = 0.02;

    hull() {
        // vorderer Streifen direkt an der Rückseite der Frontplatte
        translate([x_center, y_front_center, plate_t + eps/2])
            cube([rail_w, top_wall_t, eps], center = true);

        // hinterer Streifen weiter hinten und höher
        translate([x_center, y_back_center, plate_t + rim_depth - eps/2])
            cube([rail_w, top_wall_t, eps], center = true);
    }
}

module left_top_rail() {
    top_sloped_rail(x_left_rail_center, top_rail_w);
}

module right_top_rail() {
    top_sloped_rail(x_right_rail_center, top_rail_w);
}

// =========================
// PRINTER-CUTOUT 3D
// =========================

module printer_cutout_3d() {
    translate([0, 0, -0.1])
        linear_extrude(height = plate_t + rim_depth + 0.2, convexity = 10)
            printer_cutout_2d();
}

// =========================
// GESAMTTEIL
// =========================

module plate() {
    difference() {
        union() {
            front_plate();
            left_wall();
            right_wall();
            bottom_wall();
            left_top_rail();
            right_top_rail();
        }

        printer_cutout_3d();
    }
}

// =========================
// PREVIEW
// =========================

module dummy_printer() {
    color([0.15, 0.15, 0.15, 0.55])
        union() {
            // Druckerkörper hinter der Platte
            translate([0, 0, plate_t])
                linear_extrude(height = dummy_body_d, convexity = 10)
                    rounded_rect_2d(dummy_body_w, dummy_body_h, 1.0);

            // Frontüberstand vor der Platte
            translate([0, 0, -dummy_bezel_t])
                linear_extrude(height = dummy_bezel_t, convexity = 10)
                    rounded_rect_2d(dummy_bezel_w, dummy_bezel_h, 1.5);
        }
}

module preview() {
    plate();
    dummy_printer();
}

// =========================
// OUTPUT
// =========================

if (part == "preview") {
    preview();
} else {
    plate();
}

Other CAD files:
3dprint/top_panel.scad
3dprint/turntable.scad

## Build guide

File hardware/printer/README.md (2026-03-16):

# printer

Pi-side setup script for Twinr's thermal printer queue and raw paper-output smoke checks.

## Responsibility

`printer` owns:
- detect or accept the printer device URI for CUPS setup
- create the raw Twinr printer queue and optional default queue
- run a short raw print smoke test for operator confirmation

`printer` does **not** own:
- receipt formatting in `src/twinr/hardware/printer.py`
- reminder or print-trigger policy
- audio, display, or GPIO setup

## Key files

| File | Purpose |
|---|---|
| [setup_printer.sh](./setup_printer.sh) | Configure raw CUPS queue |

## Usage

```bash
sudo ./hardware/printer/setup_printer.sh --default --test
sudo ./hardware/printer/setup_printer.sh --queue Thermal_GP58 --device-uri 'usb://Gprinter/GP-58?serial=WTTING%20'
```

## See also

- [Top-level hardware README](../README.md)
- [Runtime printer adapter](../../src/twinr/hardware/printer.py)

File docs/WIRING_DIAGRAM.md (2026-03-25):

# Wiring Diagram

Compact wiring overview for Twinr's current embodied prototype direction:
HDMI mini-screen, Pi AI Camera, ReSpeaker XVF3800, buttons, PIR, thermal
printer, and optional body-rotation servo.

The older Waveshare e-paper path is not shown here.

```mermaid
flowchart TD
    PSU5["5V / 3A+ Pi Power"] --> PI["Raspberry Pi 4 / 5"]
    HDMI5["5V screen power<br/>if required"] --> SCREEN["4\" HDMI mini-screen"]
    PI -->|"HDMI"| SCREEN
    PI -->|"CSI ribbon"| CAM["Pi AI Camera (IMX500)"]
    PI -->|"USB"| RES["ReSpeaker XVF3800"]
    RES -->|"audio out / compatible playback path"| SPK["Speaker / powered speaker"]
    PI -->|"USB data"| PRN["Thermal printer<br/>DFRobot DFR0503-EN"]
    PRNPSU["9-24V printer PSU"] --> PRN
    PI -->|"GPIO23"| BTN1["Green button"]
    PI -->|"GPIO22"| BTN2["Yellow / Print button"]
    BTN1 -->|"other side"| GND["Shared GND"]
    BTN2 -->|"other side"| GND
    PI -->|"GPIO26"| PIR["PIR OUT"]
    PIRV["PIR VCC"] --> PIR
    PIR --> GND
    PI -->|"USB"| MAE["Pololu Mini Maestro (preferred)"]
    MAE -->|"servo signal"| SERVO["Body rotation servo"]
    SRVPSU["Servo PSU"] --> SERVO
    PI -.->|"optional direct SIG on GPIO18"| SERVO
    GND --> PIR
    GND --> MAE
```

## Current GPIO map

| Function | BCM GPIO | Physical pin |
|---|---:|---:|
| Green / "Hey" button | `GPIO23` | `16` |
| Yellow / "Print" button | `GPIO22` | `15` |
| PIR motion `OUT` | `GPIO26` | `37` |
| Optional direct servo `SIG` | `GPIO18` | `12` |

## Wiring notes

- Raspberry Pi GPIO must stay at or below `3.3V`.
- Use shared ground where the Pi and an external controller/sensor need the same reference.
- Power the thermal printer from its own supply.
- Power a large servo from its own supply.
- Prefer the `Pololu Mini Maestro` path for calm, safer servo control.
- Some HDMI mini-screens need separate USB power in addition to HDMI.
- The ReSpeaker playback side depends on the exact board / speaker setup; use a compatible speaker or powered playback path.

## Bring-up commands

```bash
cd /twinr
sudo hardware/display/setup_display.sh --env-file /twinr/.env --driver hdmi_wayland
sudo hardware/mic/setup_audio.sh --env-file /twinr/.env --test
sudo hardware/mic/setup_respeaker_access.sh
hardware/buttons/setup_buttons.sh --green 23 --yellow 22
hardware/pir/setup_pir.sh --motion 26 --probe
sudo hardware/printer/setup_printer.sh --default --test
python3 hardware/piaicam/smoke_piaicam.py
sudo hardware/servo/setup_pololu_maestro.sh
```

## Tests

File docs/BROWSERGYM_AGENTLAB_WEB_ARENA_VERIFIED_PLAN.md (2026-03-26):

# Twinr External Browser Benchmark Plan

This document defines the first external benchmark integration path for Twinr's
browser agent. The goal is to measure Twinr against an existing benchmark stack
instead of building a new internal benchmark website or a large custom harness.

## Decision

Use:

- `AgentLab` as the experiment/evaluation runner
- `BrowserGym` as the benchmark environment layer
- `WebArena-Verified` as the first external target benchmark

This is the smallest practical path to a real external score because:

- BrowserGym already exposes maintained benchmark packages and task execution
  APIs.
- AgentLab is the official experiment layer above BrowserGym and already
  supports WebArena-family benchmarks.
- WebArena-Verified is self-hosted and reproducible, which makes it a better
  first external score than noisier live-web benchmarks.

## What "No New Harness" Means Here

Twinr should not build a second benchmark website, a second scoring system, or a
bespoke task runner that duplicates AgentLab/BrowserGym.

The only Twinr-specific code we should add is a thin adapter that lets AgentLab
or BrowserGym call the current Twinr browser agent.

Allowed Twinr-owned code:

- one adapter from BrowserGym observations/actions to Twinr browser calls
- one small launch/config wrapper for repeatable local runs
- a small set of contract tests for the adapter

Not allowed in this phase:

- a Twinr-owned clone of WebArena
- a Twinr-owned benchmark scorer
- a large parallel experiment framework duplicating AgentLab
- moving benchmark websites into tracked repo paths

## Repo Safety And Gitignore Invariant

Tracked code must stay separate from local browser-workspace state.

Tracked paths:

- `agentic_tools/` for benchmark launch helpers and reproducibility wrappers
- `test/` for narrow adapter tests
- `docs/` for the integration plan and later benchmark runbooks

Ignored local workspaces:

- `/browser_automation/**`
- `/web_automation/**`

That means:

- benchmark sites, docker state, cloned benchmark repos, screenshots, traces,
  and local experiment outputs stay outside tracked source code
- the current Twinr browser workspace continues to stay ignored
- any future alternate web-automation workspace also stays ignored

## Target Architecture

### 1. Twinr benchmark adapter

Add a small tracked adapter layer under `agentic_tools/` that owns:

- reading benchmark task instructions
- invoking Twinr's current browser tool/runtime path
- translating Twinr results into the benchmark runner's expected outcome shape
- capturing run metadata for reproducibility

This adapter should not contain browser policy logic. It only bridges external
benchmark APIs to the existing Twinr browser runtime.

### 2. External benchmark workspace

Keep the actual benchmark stack outside tracked code, inside ignored workspaces.

Recommended local layout:

- `/browser_automation/benchmarks/agentlab/`
- `/browser_automation/benchmarks/browsergym/`
- `/browser_automation/benchmarks/webarena_verified/`

Optional future alternative:

- `/web_automation/benchmarks/...`

Twinr should treat these as disposable local environments, not as repo source of
truth.

### 3. First benchmark target

Start with `WebArena-Verified`.

Reason:

- self-hosted and reproducible
- broad enough to be meaningful
- less noisy than open live-web suites
- already sits on the BrowserGym/AgentLab path we want anyway

## Implementation Phases

### Phase 0: Environment spike

Objective:

- prove that the benchmark stack boots locally without touching Twinr runtime
  logic

Steps:

1. Create the ignored local benchmark workspace under
   `/browser_automation/benchmarks/`.
2. Install AgentLab, BrowserGym, Playwright, and the WebArena-Verified
   benchmark prerequisites there.
3. Bring up one official benchmark environment and run one reference agent from
   AgentLab unchanged.

Exit criteria:

- AgentLab can launch one benchmark task successfully
- BrowserGym environment resets correctly
- no tracked repo files are required for benchmark site hosting

### Phase 1: Thin Twinr adapter

Objective:

- let AgentLab run Twinr as just another agent

Steps:

1. Add a small tracked adapter module under `agentic_tools/`.
2. Feed the benchmark task instruction into Twinr's browser-entry path.
3. Map benchmark step budget, timeout budget, and final result fields into the
   Twinr request.
4. Return Twinr's completion/failure result in the format expected by the
   benchmark runner.

Exit criteria:

- one BrowserGym task can be executed through Twinr end to end
- adapter code stays thin and contains no duplicated browser policy
- adapter tests prove request/result translation

### Phase 2: WebArena-Verified smoke

Objective:

- obtain the first honest external benchmark result

Steps:

1. Run a very small WebArena-Verified subset first.
2. Capture exact package versions, benchmark version, commit hash, model id, and
   Twinr config.
3. Store only the summarized benchmark result and report artifacts in the repo's
   normal artifact stores; keep raw benchmark environment state in ignored
   workspace paths.

Exit criteria:

- one reproducible Twinr study exists against WebArena-Verified
- result can be re-run from one documented command sequence

### Phase 3: Repeatable Twinr command

Objective:

- turn the spike into one stable operator/developer workflow

Steps:

1. Add a small `agentic_tools/` launcher or wrapper script.
2. Add a doc/runbook with prerequisites, benchmark workspace location, and exact
   commands.
3. Keep all heavy benchmark assets external to tracked code.

Exit criteria:

- one developer can reproduce the benchmark run without inventing setup steps

## Verification Strategy

### Local verification

- contract test for the adapter request/result mapping
- one single-task BrowserGym smoke through Twinr
- one tiny WebArena-Verified subset run

### Pi verification

Do not start with full benchmark hosting on the Pi.

Pi acceptance is only required if the adapter changes runtime-facing Twinr code.
If that happens:

- deploy the changed Twinr code to `/twinr`
- prove that the normal Twinr browser runtime still passes the existing local Pi
  acceptance gates
- optionally run one narrow adapter smoke on the Pi if the runtime path itself
  changed

### Reproducibility metadata

For every benchmark run capture:

- Twinr git commit
- AgentLab version
- BrowserGym version
- benchmark package/version
- model id
- timeout and step-budget settings
- command line used

## Why Not Start With Live-Web Benchmarks

Not first.

Benchmarks like AssistantBench or other live-web suites are useful later, but
they introduce:

- region variance
- language variance
- silent site changes
- harder result comparison over time

That makes them a bad first external score for Twinr.

## Recommended Tracked File Layout

Keep the tracked integration minimal:

- `agentic_tools/browser_benchmarks/`
  - environment checks
  - launcher wrapper
  - reproducibility capture
- `test/test_browsergym_adapter.py`
  - adapter contract tests
- `docs/BROWSERGYM_AGENTLAB_WEB_ARENA_VERIFIED_PLAN.md`
  - this plan

Keep all benchmark environments and cloned benchmark repos ignored under the root
workspace paths.

## Non-Goals For This First Pass

- no WorkArena integration yet
- no VisualWebArena integration yet
- no live-web benchmark first
- no leaderboard optimization
- no benchmark-shaped Twinr logic

## Success Criteria

This phase is complete when:

1. Twinr can be launched by AgentLab through a thin adapter.
2. WebArena-Verified can run against Twinr without a Twinr-owned benchmark
   website or scorer.
3. All heavy browser/web automation workspaces remain ignored by git.
4. Twinr still passes its existing internal browser acceptance gates after the
   adapter lands.

## Primary Sources

- BrowserGym docs: <https://browsergym.readthedocs.io/latest/>
- BrowserGym repo: <https://github.com/ServiceNow/BrowserGym>
- AgentLab repo: <https://github.com/ServiceNow/AgentLab>
- WebArena-x overview: <https://webarena.dev/>
- WebArena paper: <https://arxiv.org/abs/2307.13854>

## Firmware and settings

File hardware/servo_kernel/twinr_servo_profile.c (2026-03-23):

/*
 * twinr_servo_profile.c - bounded motion probe for the Twinr servo kernel module
 *
 * This small C utility drives /sys/class/twinr_servo/servo0 with an eased
 * point-to-point move. It exists to keep motion-profile experimentation out of
 * the kernel module itself while still avoiding Python or high-level runtime
 * dependencies during Pi acceptance work.
 *
 * The profile supports:
 * - a minimum-jerk trajectory between start and target pulse widths
 * - micro-step gating so tiny updates are skipped
 * - an optional short breakaway pulse to overcome deadband/stiction at motion start
 * - persisted last-target tracking so the next bounded move starts from the
 *   last commanded end position instead of blindly snapping to a stale start
 * - bounded settle time followed by clean disable + GPIO release
 */

#define _POSIX_C_SOURCE 200809L

#include <errno.h>
#include <getopt.h>
#include <limits.h>
#include <signal.h>
#include <stdbool.h>
#include <stdint.h>
#include <stdio.h>
#include <stdlib.h>
#include <string.h>
#include <time.h>
#include <unistd.h>

#define DEFAULT_SYSFS_ROOT "/sys/class/twinr_servo/servo0"
#define DEFAULT_GPIO 18
#define DEFAULT_PERIOD_US 20000
#define DEFAULT_SETTLE_MS 1000
#define DEFAULT_CADENCE_MS 52
#define DEFAULT_GATE_US 6
#define DEFAULT_BREAKAWAY_US 18
#define DEFAULT_BREAKAWAY_HOLD_MS 140
#define DEFAULT_STATE_FILE "/var/tmp/twinr_servo_profile_last_us"

struct motion_config {
	const char *sysfs_root;
	const char *state_file;
	int gpio;
	int period_us;
	int start_us;
	int target_us;
	int duration_ms;
	int settle_ms;
	int cadence_ms;
	int gate_us;
	int breakaway_us;
	int breakaway_hold_ms;
	bool override_state;
	bool start_explicit;
	bool disable_state_tracking;
	bool verbose;
};

struct cleanup_state {
	const char *sysfs_root;
	bool armed;
};

static struct cleanup_state g_cleanup = {0};

static void usage(FILE *stream, const char *argv0)
{
	fprintf(
		stream,
		"Usage: %s --start-us N --target-us N --duration-ms N [options]\n"
		"\n"
		"Options:\n"
		"  --sysfs-root PATH          Sysfs device root (default %s)\n"
		"  --gpio N                   GPIO line to claim (default %d)\n"
		"  --period-us N              PWM period in microseconds (default %d)\n"
		"  --state-file PATH          Persisted last-target file (default %s)\n"
		"  --no-state                 Disable persisted last-target safety checks\n"
		"  --override-state           Allow --start-us to differ from the persisted state\n"
		"  --settle-ms N              Hold at target before release (default %d)\n"
		"  --cadence-ms N             Control cadence in milliseconds (default %d)\n"
		"  --gate-us N                Skip updates below this delta (default %d)\n"
		"  --breakaway-us N           Initial kick toward target in microseconds (default %d)\n"
		"  --breakaway-hold-ms N      Hold the kick before easing (default %d)\n"
		"  --verbose                  Print each committed pulse write\n",
		argv0,
		DEFAULT_SYSFS_ROOT,
		DEFAULT_GPIO,
		DEFAULT_PERIOD_US,
		DEFAULT_STATE_FILE,
		DEFAULT_SETTLE_MS,
		DEFAULT_CADENCE_MS,
		DEFAULT_GATE_US,
		DEFAULT_BREAKAWAY_US,
		DEFAULT_BREAKAWAY_HOLD_MS);
}

static int write_attr(const char *root, const char *name, int value)
{
	char path[PATH_MAX];
	FILE *file;

	if (snprintf(path, sizeof(path), "%s/%s", root, name) >= (int)sizeof(path)) {
		fprintf(stderr, "path too long for %s\n", name);
		return -ENAMETOOLONG;
	}

	file = fopen(path, "w");
	if (file == NULL) {
		perror(path);
		return -errno;
	}
	if (fprintf(file, "%d", value) < 0) {
		perror(path);
		fclose(file);
		return -EIO;
	}
	if (fclose(file) != 0) {
		perror(path);
		return -errno;
	}
	return 0;
}

static void sleep_ms(int milliseconds)
{
	struct timespec request;

	if (milliseconds <= 0)
		return;
	request.tv_sec = milliseconds / 1000;
	request.tv_nsec = (long)(milliseconds % 1000) * 1000000L;
	while (nanosleep(&request, &request) != 0) {
		if (errno != EINTR)
			break;
	}
}

static void cleanup_servo(void)
{
	if (!g_cleanup.armed || g_cleanup.sysfs_root == NULL)
		return;
	(void)write_attr(g_cleanup.sysfs_root, "enabled", 0);
	(void)write_attr(g_cleanup.sysfs_root, "gpio", -1);
	g_cleanup.armed = false;
}

static void handle_signal(int signo)
{
	(void)signo;
	cleanup_servo();
	_exit(128 + signo);
}

static double min_jerk(double t)
{
	double t2 = t * t;
	double t3 = t2 * t;
	double t4 = t3 * t;
	double t5 = t4 * t;

	return 10.0 * t3 - 15.0 * t4 + 6.0 * t5;
}

static int rounded_lerp(int start, int target, double weight)
{
	double value = (double)start + ((double)target - (double)start) * weight;

	return (int)(value >= 0.0 ? value + 0.5 : value - 0.5);
}

static int abs_int(int value)
{
	return value < 0 ? -value : value;
}

static int parse_int(const char *text, const char *label)
{
	char *end = NULL;
	long value;

	errno = 0;
	value = strtol(text, &end, 10);
	if (errno != 0 || end == text || *end != '\0' || value < INT_MIN || value > INT_MAX) {
		fprintf(stderr, "invalid %s: %s\n", label, text);
		exit(2);
	}
	return (int)value;
}

static int load_state_file(const char *path, int *pulse_us)
{
	FILE *file;
	char line[64];
	char *end = NULL;
	long value;

	file = fopen(path, "r");
	if (file == NULL) {
		if (errno == ENOENT)
			return 1;
		perror(path);
		return -errno;
	}
	if (fgets(line, sizeof(line), file) == NULL) {
		if (fclose(file) != 0)
			perror(path);
		fprintf(stderr, "failed to read %s\n", path);
		return -EIO;
	}
	if (fclose(file) != 0) {
		perror(path);
		return -errno;
	}

	errno = 0;
	value = strtol(line, &end, 10);
	if (errno != 0 || end == line || (*end != '\0' && *end != '\n') || value < INT_MIN || value > INT_MAX) {
		fprintf(stderr, "invalid persisted state in %s: %s\n", path, line);
		return -EINVAL;
	}
	*pulse_us = (int)value;
	return 0;
}

static int save_state_file(const char *path, int pulse_us)
{
	FILE *file;

	file = fopen(path, "w");
	if (file == NULL) {
		perror(path);
		return -errno;
	}
	if (fprintf(file, "%d\n", pulse_us) < 0) {
		perror(path);
		fclose(file);
		return -EIO;
	}
	if (fclose(file) != 0) {
		perror(path);
		return -errno;
	}
	return 0;
}

static void parse_args(int argc, char **argv, struct motion_config *config)
{
	static const struct option options[] = {
		{"sysfs-root", required_argument, NULL, 'r'},
		{"gpio", required_argument, NULL, 'g'},
		{"period-us", required_argument, NULL, 'p'},
		{"state-file", required_argument, NULL, 'f'},
		{"no-state", no_argument, NULL, 'n'},
		{"override-state", no_argument, NULL, 'o'},
		{"start-us", required_argument, NULL, 's'},
		{"target-us", required_argument, NULL, 't'},
		{"duration-ms", required_argument, NULL, 'd'},
		{"settle-ms", required_argument, NULL, 'S'},
		{"cadence-ms", required_argument, NULL, 'c'},
		{"gate-us", required_argument, NULL, 'G'},
		{"breakaway-us", required_argument, NULL, 'b'},
		{"breakaway-hold-ms", required_argument, NULL, 'B'},
		{"verbose", no_argument, NULL, 'v'},
		{"help", no_argument, NULL, 'h'},
		{NULL, 0, NULL, 0},
	};
	bool start_seen = false;
	bool target_seen = false;
	bool duration_seen = false;
	int opt;

		*config = (struct motion_config){
		.sysfs_root = DEFAULT_SYSFS_ROOT,
		.state_file = DEFAULT_STATE_FILE,
		.gpio = DEFAULT_GPIO,
		.period_us = DEFAULT_PERIOD_US,
		.settle_ms = DEFAULT_SETTLE_MS,
		.cadence_ms = DEFAULT_CADENCE_MS,
		.gate_us = DEFAULT_GATE_US,
		.breakaway_us = DEFAULT_BREAKAWAY_US,
		.breakaway_hold_ms = DEFAULT_BREAKAWAY_HOLD_MS,
	};

	while ((opt = getopt_long(argc, argv, "r:g:p:f:nos:t:d:S:c:G:b:B:vh", options, NULL)) != -1) {
		switch (opt) {
		case 'r':
			config->sysfs_root = optarg;
			break;
		case 'g':
			config->gpio = parse_int(optarg, "gpio");
			break;
		case 'p':
			config->period_us = parse_int(optarg, "period-us");
			break;
		case 'f':
			config->state_file = optarg;
			break;
		case 'n':
			config->disable_state_tracking = true;
			break;
		case 'o':
			config->override_state = true;
			break;
		case 's':
			config->start_us = parse_int(optarg, "start-us");
			start_seen = true;
			config->start_explicit = true;
			break;
		case 't':
			config->target_us = parse_int(optarg, "target-us");
			target_seen = true;
			break;
		case 'd':
			config->duration_ms = parse_int(optarg, "duration-ms");
			duration_seen = true;
			break;
		case 'S':
			config->settle_ms = parse_int(optarg, "settle-ms");
			break;
		case 'c':
			config->cadence_ms = parse_int(optarg, "cadence-ms");
			break;
		case 'G':
			config->gate_us = parse_int(optarg, "gate-us");
			break;
		case 'b':
			config->breakaway_us = parse_int(optarg, "breakaway-us");
			break;
		case 'B':
			config->breakaway_hold_ms = parse_int(optarg, "breakaway-hold-ms");
			break;
		case 'v':
			config->verbose = true;
			break;
		case 'h':
			usage(stdout, argv[0]);
			exit(0);
		default:
			usage(stderr, argv[0]);
			exit(2);
		}
	}

	if (!target_seen || !duration_seen) {
		usage(stderr, argv[0]);
		exit(2);
	}
	if (config->duration_ms <= 0 || config->cadence_ms <= 0 || config->gate_us < 0) {
		fprintf(stderr, "duration/cadence must be > 0 and gate must be >= 0\n");
		exit(2);
	}
	if (!config->disable_state_tracking) {
		int persisted_start_us = 0;
		int state_rc = load_state_file(config->state_file, &persisted_start_us);

		if (state_rc < 0)
			exit(2);
		if (state_rc == 0) {
			if (start_seen) {
				if (config->start_us != persisted_start_us && !config->override_state) {
					fprintf(
						stderr,
						"start-us %d disagrees with persisted state %d in %s; "
						"use --override-state to force a reset\n",
						config->start_us,
						persisted_start_us,
						config->state_file);
					exit(2);
				}
			} else {
				config->start_us = persisted_start_us;
				start_seen = true;
			}
		}
	}
	if (!start_seen) {
		fprintf(stderr, "start-us is required when no persisted state is available\n");
		exit(2);
	}
}

static int maybe_write_pulse(
	const struct motion_config *config,
	int pulse_us,
	int *last_written_us,
	bool force)
{
	if (!force && abs_int(pulse_us - *last_written_us) < config->gate_us)
		return 0;
	if (config->verbose)
		printf("pulse_width_us=%d\n", pulse_us);
	if (write_attr(config->sysfs_root, "pulse_width_us", pulse_us) != 0)
		return -1;
	*last_written_us = pulse_us;
	return 0;
}

static int run_profile(const struct motion_config *config)
{
	int direction = 0;
	int last_written_us = config->start_us;
	int profile_start_us = config->start_us;
	int steps = config->duration_ms / config->cadence_ms;
	int breakaway_target;
	int step;

	if (write_attr(config->sysfs_root, "gpio", config->gpio) != 0)
		return 1;
	if (write_attr(config->sysfs_root, "period_us", config->period_us) != 0)
		return 1;
	if (write_attr(config->sysfs_root, "pulse_width_us", config->start_us) != 0)
		return 1;
	if (write_attr(config->sysfs_root, "enabled", 1) != 0)
		return 1;
	g_cleanup.sysfs_root = config->sysfs_root;
	g_cleanup.armed = true;

	sleep_ms(800);

	if (config->target_us > config->start_us)
		direction = 1;
	else if (config->target_us < config->start_us)
		direction = -1;

	if (direction != 0 && config->breakaway_us > 0 && config->breakaway_hold_ms > 0) {
		int remaining_us = abs_int(config->target_us - config->start_us);
		int kick_us = config->breakaway_us < remaining_us ? config->breakaway_us : remaining_us;

		breakaway_target = config->start_us + direction * kick_us;
		if (maybe_write_pulse(config, breakaway_target, &last_written_us, false) != 0)
			return 1;
		profile_start_us = breakaway_target;
		sleep_ms(config->breakaway_hold_ms);
	}

	if (steps < 1)
		steps = 1;

	for (step = 0; step <= steps; ++step) {
		double t = (double)step / (double)steps;
		int pulse_us = rounded_lerp(profile_start_us, config->target_us, min_jerk(t));

		if (maybe_write_pulse(config, pulse_us, &last_written_us, step == steps) != 0)
			return 1;
		if (step < steps)
			sleep_ms(config->cadence_ms);
	}

	sleep_ms(config->settle_ms);
	if (!config->disable_state_tracking && save_state_file(config->state_file, config->target_us) != 0)
		return 1;
	return 0;
}

int main(int argc, char **argv)
{
	struct motion_config config;
	struct sigaction action;
	int rc;

	parse_args(argc, argv, &config);

	memset(&action, 0, sizeof(action));
	action.sa_handler = handle_signal;
	sigaction(SIGINT, &action, NULL);
	sigaction(SIGTERM, &action, NULL);

	rc = run_profile(&config);
	cleanup_servo();
	return rc;
}

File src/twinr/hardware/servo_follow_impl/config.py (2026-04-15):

"""Normalize Twinr config into one bounded attention-servo config object."""

from __future__ import annotations

from dataclasses import dataclass
from pathlib import Path

from twinr.agent.base_agent.config import TwinrConfig

from .constants import (
    _DEFAULT_CENTER_PULSE_WIDTH_US,
    _DEFAULT_CONTINUOUS_MAX_SPEED_DEGREES_PER_S,
    _DEFAULT_CONTINUOUS_MAX_SPEED_PULSE_DELTA_US,
    _DEFAULT_CONTINUOUS_MIN_SPEED_PULSE_DELTA_US,
    _DEFAULT_CONTINUOUS_RETURN_TO_ZERO_AFTER_S,
    _DEFAULT_CONTINUOUS_SLOW_ZONE_DEGREES,
    _DEFAULT_CONTINUOUS_STOP_TOLERANCE_DEGREES,
    _DEFAULT_CONTROL_MODE,
    _DEFAULT_DEADBAND,
    _DEFAULT_ESTIMATED_ZERO_MAX_UNCERTAINTY_DEGREES,
    _DEFAULT_ESTIMATED_ZERO_MOVE_DUTY_CYCLE,
    _DEFAULT_ESTIMATED_ZERO_MOVE_PERIOD_S,
    _DEFAULT_ESTIMATED_ZERO_MOVE_PULSE_DELTA_US,
    _DEFAULT_ESTIMATED_ZERO_SETTLE_TOLERANCE_DEGREES,
    _DEFAULT_ESTIMATED_ZERO_SPEED_SCALE,
    _DEFAULT_EXIT_ACTIVATION_DELAY_S,
    _DEFAULT_EXIT_COOLDOWN_S,
    _DEFAULT_EXIT_FOLLOW_MAX_DEGREES,
    _DEFAULT_EXIT_REACQUIRE_CENTER_TOLERANCE,
    _DEFAULT_EXIT_SETTLE_HOLD_S,
    _DEFAULT_EXIT_VISIBLE_BOX_EDGE_THRESHOLD,
    _DEFAULT_EXIT_VISIBLE_EDGE_THRESHOLD,
    _DEFAULT_FOLLOW_EXIT_ONLY,
    _DEFAULT_IDLE_RELEASE_S,
    _DEFAULT_LOSS_EXTRAPOLATION_GAIN,
    _DEFAULT_LOSS_EXTRAPOLATION_S,
    _DEFAULT_MAX_ACCELERATION_US_PER_S2,
    _DEFAULT_MAX_JERK_US_PER_S3,
    _DEFAULT_MAX_PULSE_WIDTH_US,
    _DEFAULT_MAX_STEP_US,
    _DEFAULT_MAX_VELOCITY_US_PER_S,
    _DEFAULT_MECHANICAL_RANGE_DEGREES,
    _DEFAULT_MIN_COMMAND_DELTA_US,
    _DEFAULT_MIN_CONFIDENCE,
    _DEFAULT_MIN_PULSE_WIDTH_US,
    _DEFAULT_REFERENCE_INTERVAL_S,
    _DEFAULT_REST_MAX_ACCELERATION_US_PER_S2,
    _DEFAULT_REST_MAX_JERK_US_PER_S3,
    _DEFAULT_REST_MAX_VELOCITY_US_PER_S,
    _DEFAULT_SERVO_DRIVER,
    _DEFAULT_SETTLED_RELEASE_S,
    _DEFAULT_SOFT_LIMIT_MARGIN_US,
    _DEFAULT_STATE_PATH,
    _DEFAULT_TARGET_HOLD_S,
    _DEFAULT_TARGET_SMOOTHING_S,
    _DEFAULT_VISIBLE_RECENTER_CENTER_TOLERANCE,
    _DEFAULT_VISIBLE_RECENTER_INTERVAL_S,
    _DEFAULT_VISIBLE_RETARGET_COOLDOWN_S,
    _DEFAULT_VISIBLE_RETARGET_TOLERANCE_US,
)

from .common import _bounded_float, _bounded_int

@dataclass(frozen=True, slots=True)
class AttentionServoConfig:
    """Store bounded attention-servo tuning from the global Twinr config."""

    enabled: bool = False
    driver: str = _DEFAULT_SERVO_DRIVER
    control_mode: str = _DEFAULT_CONTROL_MODE
    maestro_device: str | None = None
    maestro_transport_requested: bool = False
    peer_base_url: str | None = None
    peer_timeout_s: float = 1.5
    state_path: str = _DEFAULT_STATE_PATH
    estimated_zero_max_uncertainty_degrees: float = _DEFAULT_ESTIMATED_ZERO_MAX_UNCERTAINTY_DEGREES
    estimated_zero_settle_tolerance_degrees: float = _DEFAULT_ESTIMATED_ZERO_SETTLE_TOLERANCE_DEGREES
    estimated_zero_speed_scale: float = _DEFAULT_ESTIMATED_ZERO_SPEED_SCALE
    estimated_zero_move_pulse_delta_us: int = _DEFAULT_ESTIMATED_ZERO_MOVE_PULSE_DELTA_US
    estimated_zero_move_period_s: float = _DEFAULT_ESTIMATED_ZERO_MOVE_PERIOD_S
    estimated_zero_move_duty_cycle: float = _DEFAULT_ESTIMATED_ZERO_MOVE_DUTY_CYCLE
    continuous_return_to_zero_after_s: float = _DEFAULT_CONTINUOUS_RETURN_TO_ZERO_AFTER_S
    gpio_chip: str = "gpiochip0"
    gpio: int | None = None
    invert_direction: bool = False
    target_hold_s: float = _DEFAULT_TARGET_HOLD_S
    loss_extrapolation_s: float = _DEFAULT_LOSS_EXTRAPOLATION_S
    loss_extrapolation_gain: float = _DEFAULT_LOSS_EXTRAPOLATION_GAIN
    min_confidence: float = _DEFAULT_MIN_CONFIDENCE
    hold_min_confidence: float = _DEFAULT_MIN_CONFIDENCE
    deadband: float = _DEFAULT_DEADBAND
    min_pulse_width_us: int = _DEFAULT_MIN_PULSE_WIDTH_US
    center_pulse_width_us: int = _DEFAULT_CENTER_PULSE_WIDTH_US
    max_pulse_width_us: int = _DEFAULT_MAX_PULSE_WIDTH_US
    max_step_us: int = _DEFAULT_MAX_STEP_US
    target_smoothing_s: float = _DEFAULT_TARGET_SMOOTHING_S
    max_velocity_us_per_s: float = _DEFAULT_MAX_VELOCITY_US_PER_S
    max_acceleration_us_per_s2: float = _DEFAULT_MAX_ACCELERATION_US_PER_S2
    max_jerk_us_per_s3: float = _DEFAULT_MAX_JERK_US_PER_S3
    rest_max_velocity_us_per_s: float = _DEFAULT_REST_MAX_VELOCITY_US_PER_S
    rest_max_acceleration_us_per_s2: float = _DEFAULT_REST_MAX_ACCELERATION_US_PER_S2
    rest_max_jerk_us_per_s3: float = _DEFAULT_REST_MAX_JERK_US_PER_S3
    min_command_delta_us: int = _DEFAULT_MIN_COMMAND_DELTA_US
    visible_retarget_tolerance_us: int = _DEFAULT_VISIBLE_RETARGET_TOLERANCE_US
    visible_retarget_cooldown_s: float = _DEFAULT_VISIBLE_RETARGET_COOLDOWN_S
    reference_interval_s: float = _DEFAULT_REFERENCE_INTERVAL_S
    soft_limit_margin_us: int = _DEFAULT_SOFT_LIMIT_MARGIN_US
    idle_release_s: float = _DEFAULT_IDLE_RELEASE_S
    settled_release_s: float = _DEFAULT_SETTLED_RELEASE_S
    follow_exit_only: bool = _DEFAULT_FOLLOW_EXIT_ONLY
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

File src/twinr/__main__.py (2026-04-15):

"""Bootstrap the Twinr command-line entrypoint.

This module keeps argument parsing and high-level command dispatch at the
package root so operators can launch Twinr via ``python -m twinr`` or the
installed ``twinr`` script. Runtime behavior stays in the focused subsystem
packages that this bootstrap imports on demand.
"""

# pylint: disable=no-name-in-module

from __future__ import annotations

import argparse
import os
from pathlib import Path
import sys
from threading import Lock
from time import monotonic
from typing import Any, Callable, cast

from twinr.runtime_paths import prime_raspberry_pi_system_site_packages

prime_raspberry_pi_system_site_packages()

from twinr.agent.base_agent.config import TwinrConfig  # noqa: E402
from twinr.ops.locks import TwinrInstanceAlreadyRunningError  # noqa: E402
from twinr.runtime_host import (  # noqa: E402
    RUNTIME_SUPERVISOR_ENV_KEY as _RUNTIME_SUPERVISOR_ENV_KEY,
    is_raspberry_pi_host as _runtime_host_is_raspberry_pi_host,
    should_enable_display_surface as _should_enable_display_surface,
    uses_pi_runtime_root as _runtime_host_uses_pi_runtime_root,
)
_WATCHDOG_ALREADY_RUNNING_EXIT_CODE = 75


def build_parser() -> argparse.ArgumentParser:
    """Build the authoritative CLI parser for Twinr runtime commands."""

    parser = argparse.ArgumentParser(description="Twinr bootstrap runtime")
    parser.add_argument("--env-file", default=".env", help="Path to the .env file")
    parser.add_argument(
        "--demo-transcript",
        help="Run a simple end-to-end placeholder flow for a transcript",
    )
    parser.add_argument(
        "--openai-prompt",
        help="Send a prompt through the OpenAI backend",
    )
    parser.add_argument(
        "--vision-prompt",
        help="Send a prompt plus one or more images through the OpenAI backend",
    )
    parser.add_argument(
        "--vision-image",
        action="append",
        type=Path,
        default=[],
        help="Attach a local image file; repeat for multiple images",
    )
    parser.add_argument(
        "--vision-camera-capture",
        action="store_true",
        help="Capture a fresh camera image and attach it as the first vision input",
    )
    parser.add_argument(
        "--vision-save-capture",
        type=Path,
        help="Optionally persist the camera image used for --vision-prompt",
    )
    parser.add_argument(
        "--camera-capture-output",
        type=Path,
        help="Capture a still image from the configured camera and write it to this path",
    )
    parser.add_argument(
        "--self-test",
        help="Run one bounded Twinr ops self-test by id and print the result.",
    )
    parser.add_argument(
        "--drone-status",
        action="store_true",
        help="Read one bounded state snapshot from the configured drone daemon.",
    )
    parser.add_argument(
        "--drone-inspect",
        help="Queue one bounded inspect mission through the configured drone daemon.",
    )
    parser.add_argument(
        "--drone-hover-test",
        action="store_true",
        help="Queue one bounded takeoff-hover-land test mission through the configured drone daemon.",
    )
    parser.add_argument(
        "--drone-cancel-mission",
        help="Cancel one existing drone mission by id.",
    )
    parser.add_argument(
        "--drone-manual-arm",
        help="Approve manual arm for one existing drone mission by id through the daemon's local ops path.",
    )
    parser.add_argument(
        "--proactive-observe-once",
        action="store_true",
        help="Capture one proactive vision observation and print the parsed fields",
    )
    parser.add_argument(
        "--proactive-audio-observe-once",
        action="store_true",
        help="Capture one proactive ambient-audio observation and print the parsed fields",
    )
    parser.add_argument(
        "--openai-web-search",
        action="store_true",
        default=None,
        help="Enable the OpenAI web search tool for --openai-prompt",
    )
    parser.add_argument(
        "--audio-file",
        type=Path,
        help="Transcribe an audio file with OpenAI speech-to-text",
    )
    parser.add_argument(
        "--tts-text",
        help="Synthesize standalone text with OpenAI text-to-speech",
    )
    parser.add_argument(
        "--tts-output",
        type=Path,
        default=Path("twinr-tts.wav"),
        help="Write synthesized speech to this file",
    )
    parser.add_argument(
        "--format-for-print",
        help="Rewrite text into a short thermal-printer format using OpenAI",
    )
    parser.add_argument(
        "--run-streaming-loop",
        action="store_true",
        help="Run the GPIO -> STT -> tool-calling LLM -> TTS -> speaker/printer loop",
    )
    parser.add_argument(
        "--run-whatsapp-channel",
        action="store_true",
        help="Run the consumer WhatsApp text channel via the Baileys worker",
    )
    parser.add_argument(
        "--run-runtime-supervisor",
        action="store_true",
        help="Run the authoritative Pi runtime supervisor for the streaming loop and remote watchdog.",
    )
    parser.add_argument(
        "--self-coding-codex-self-test",
        action="store_true",
        help="Run the bounded self_coding Codex SDK preflight on this machine.",
    )
    parser.add_argument(
        "--self-coding-live-auth-check",
        action="store_true",
        help="When used with --self-coding-codex-self-test, also run a tiny live Codex auth probe.",
    )
    parser.add_argument(
        "--self-coding-morning-briefing-acceptance",
        action="store_true",
        help="Compile and execute the minimum self_coding morning-briefing acceptance flow.",
    )
    parser.add_argument(
        "--long-term-memory-live-acceptance",
        action="store_true",
        help="Run the live synthetic-memory acceptance matrix against the real OpenAI and ChonkyDB path.",
    )
    parser.add_argument(
        "--non-voice-e2e-acceptance",
        action="store_true",
        help="Run the text-only direct/tool/memory E2E acceptance matrix and persist its artifact.",
    )
    parser.add_argument(
        "--self-coding-acceptance-capture-only",
        action="store_true",
        help="Capture morning-briefing speech in memory instead of playing it aloud during acceptance.",
    )
    parser.add_argument(
        "--run-orchestrator-server",
        action="store_true",
        help="Run the Twinr websocket orchestrator service",
    )
    parser.add_argument(
        "--orchestrator-probe-turn",
        help="Send one text turn through the websocket orchestrator and print the streamed result",
    )
    parser.add_argument(
        "--loop-duration",
        type=float,
        help="Optional max runtime in seconds for the loop commands",
    )
    parser.add_argument(
        "--run-web",
        action="store_true",
        help="Run the local Twinr settings dashboard",
    )
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

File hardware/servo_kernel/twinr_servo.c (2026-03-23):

/*
 * twinr_servo.c - Single-servo kernel driver for calm Twinr body motion
 *
 * This out-of-tree module provides one hrtimer-driven PWM output for a
 * standard hobby servo. It exists because userspace PWM helpers on the Pi did
 * not produce senior-safe movement quality for Twinr's body-follow axis.
 *
 * The module exposes one sysfs-controlled singleton device at:
 *
 *   /sys/class/twinr_servo/servo0/
 *
 * Attributes:
 *   gpio            - GPIO line number, -1 when unconfigured
 *   period_us       - Servo period in microseconds, default 20000
 *   pulse_width_us  - High pulse width in microseconds, default 1500
 *   enabled         - 0 or 1
 *
 * Change ``pulse_width_us`` while enabled to retarget the servo. Disable the
 * device before reassigning ``gpio``.
 */

#include <linux/device.h>
#include <linux/err.h>
#include <linux/gpio/consumer.h>
#include <linux/gpio/driver.h>
#include <linux/gpio/machine.h>
#include <linux/hrtimer.h>
#include <linux/init.h>
#include <linux/kernel.h>
#include <linux/kstrtox.h>
#include <linux/module.h>
#include <linux/mutex.h>
#include <linux/spinlock.h>

#define TWINR_SERVO_LABEL "twinr_servo"
#define TWINR_SERVO_DEVICE_NAME "servo0"
#define TWINR_SERVO_GPIOCHIP_LABEL "pinctrl-rp1"
#define TWINR_SERVO_DEFAULT_PERIOD_US 20000U
#define TWINR_SERVO_DEFAULT_PULSE_WIDTH_US 1500U
#define TWINR_SERVO_MIN_PERIOD_US 5000U
#define TWINR_SERVO_MAX_PERIOD_US 50000U
#define TWINR_SERVO_MIN_PULSE_WIDTH_US 500U
#define TWINR_SERVO_MAX_PULSE_WIDTH_US 2500U

struct twinr_servo_device {
	struct class *class;
	struct device *dev;
	struct gpio_desc *desc;
	struct hrtimer timer;
	struct mutex config_lock;
	spinlock_t state_lock;
	int gpio;
	bool enabled;
	bool phase_high;
	u32 period_us;
	u32 pulse_width_us;
};

static struct twinr_servo_device twinr_servo = {
	.gpio = -1,
	.period_us = TWINR_SERVO_DEFAULT_PERIOD_US,
	.pulse_width_us = TWINR_SERVO_DEFAULT_PULSE_WIDTH_US,
};

static void twinr_servo_drive_low_locked(struct twinr_servo_device *servo)
{
	if (servo->desc != NULL)
		gpiod_set_value(servo->desc, 0);
}

static void twinr_servo_stop_locked(struct twinr_servo_device *servo)
{
	unsigned long flags;

	spin_lock_irqsave(&servo->state_lock, flags);
	servo->enabled = false;
	servo->phase_high = false;
	spin_unlock_irqrestore(&servo->state_lock, flags);

	hrtimer_cancel(&servo->timer);
	twinr_servo_drive_low_locked(servo);
}

static int twinr_servo_request_gpio_locked(struct twinr_servo_device *servo, int gpio)
{
	struct gpio_chip *gpio_chip;
	struct gpio_desc *desc;
	struct gpio_device *gpio_device;
	int ret;

	if (gpio < 0) {
		if (servo->desc != NULL) {
			twinr_servo_drive_low_locked(servo);
			gpiochip_free_own_desc(servo->desc);
			servo->desc = NULL;
		}
		servo->gpio = -1;
		return 0;
	}
	if (servo->enabled)
		return -EBUSY;
	if (servo->desc != NULL && servo->gpio == gpio)
		return 0;
	if (servo->desc != NULL) {
		twinr_servo_drive_low_locked(servo);
		gpiochip_free_own_desc(servo->desc);
		servo->desc = NULL;
		servo->gpio = -1;
	}
	gpio_device = gpio_device_find_by_label(TWINR_SERVO_GPIOCHIP_LABEL);
	if (gpio_device == NULL)
		return -ENODEV;
	gpio_chip = gpio_device_get_chip(gpio_device);
	if (gpio_chip == NULL)
		return -ENODEV;
	if (gpio < 0 || gpio >= gpio_chip->ngpio)
		return -EINVAL;
	desc = gpiochip_request_own_desc(
		gpio_chip,
		gpio,
		TWINR_SERVO_LABEL,
		GPIO_LOOKUP_FLAGS_DEFAULT,
		GPIOD_OUT_LOW);
	if (IS_ERR(desc)) {
		ret = PTR_ERR(desc);
		pr_warn("twinr_servo: failed to claim %s GPIO%d: %d\n",
			TWINR_SERVO_GPIOCHIP_LABEL,
			gpio,
			ret);
		return ret;
	}
	servo->desc = desc;
	servo->gpio = gpio;
	pr_info("twinr_servo: claimed %s GPIO%d\n", TWINR_SERVO_GPIOCHIP_LABEL, gpio);
	return 0;
}

static enum hrtimer_restart twinr_servo_timer_callback(struct hrtimer *timer)
{
	struct twinr_servo_device *servo = container_of(timer, struct twinr_servo_device, timer);
	unsigned long flags;
	bool enabled;
	bool phase_high;
	u32 period_us;
	u32 pulse_width_us;
	ktime_t interval;

	spin_lock_irqsave(&servo->state_lock, flags);
	enabled = servo->enabled && servo->desc != NULL && servo->gpio >= 0;
	if (!enabled) {
		servo->phase_high = false;
		spin_unlock_irqrestore(&servo->state_lock, flags);
		return HRTIMER_NORESTART;
	}
	phase_high = !servo->phase_high;
	servo->phase_high = phase_high;
	period_us = servo->period_us;
	pulse_width_us = min(servo->pulse_width_us, servo->period_us);
	if (pulse_width_us == 0)
		pulse_width_us = 1;
	if (pulse_width_us >= period_us)
		pulse_width_us = period_us - 1;
	spin_unlock_irqrestore(&servo->state_lock, flags);

	gpiod_set_value(servo->desc, phase_high ? 1 : 0);
	interval = ktime_set(0, (phase_high ? pulse_width_us : (period_us - pulse_width_us)) * NSEC_PER_USEC);
	hrtimer_forward_now(timer, interval);
	return HRTIMER_RESTART;
}

static void twinr_servo_start_locked(struct twinr_servo_device *servo)
{
	unsigned long flags;

	spin_lock_irqsave(&servo->state_lock, flags);
	servo->phase_high = false;
	servo->enabled = true;
	spin_unlock_irqrestore(&servo->state_lock, flags);

	hrtimer_start(&servo->timer, ktime_set(0, 1), HRTIMER_MODE_REL_PINNED);
}

static ssize_t gpio_show(struct device *dev, struct device_attribute *attr, char *buf)
{
	struct twinr_servo_device *servo = dev_get_drvdata(dev);

	return sysfs_emit(buf, "%d\n", servo->gpio);
}

static ssize_t gpio_store(struct device *dev, struct device_attribute *attr, const char *buf, size_t count)
{
	struct twinr_servo_device *servo = dev_get_drvdata(dev);
	long value;
	int ret;

	ret = kstrtol(buf, 0, &value);
	if (ret)
		return ret;

	mutex_lock(&servo->config_lock);
	ret = twinr_servo_request_gpio_locked(servo, (int)value);
	mutex_unlock(&servo->config_lock);

	return ret ? ret : (ssize_t)count;
}

static ssize_t period_us_show(struct device *dev, struct device_attribute *attr, char *buf)
{
	struct twinr_servo_device *servo = dev_get_drvdata(dev);

	return sysfs_emit(buf, "%u\n", servo->period_us);
}

static ssize_t period_us_store(struct device *dev, struct device_attribute *attr, const char *buf, size_t count)
{
	struct twinr_servo_device *servo = dev_get_drvdata(dev);
	unsigned int value;
	int ret;

	ret = kstrtouint(buf, 0, &value);
	if (ret)
		return ret;
	if (value < TWINR_SERVO_MIN_PERIOD_US || value > TWINR_SERVO_MAX_PERIOD_US)
		return -ERANGE;

	mutex_lock(&servo->config_lock);
	if (servo->enabled) {
		mutex_unlock(&servo->config_lock);
		return -EBUSY;
	}
	servo->period_us = value;
	if (servo->pulse_width_us >= servo->period_us)
		servo->pulse_width_us = servo->period_us - 1;
	mutex_unlock(&servo->config_lock);

	return count;
}

static ssize_t pulse_width_us_show(struct device *dev, struct device_attribute *attr, char *buf)
{
	struct twinr_servo_device *servo = dev_get_drvdata(dev);

	return sysfs_emit(buf, "%u\n", servo->pulse_width_us);
}
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

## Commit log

2026-03-12 Expand README with shopping list and wiring guide
    Added detailed shopping list and wiring instructions for TWINR prototype.
2026-03-13 Add Twinr ops, tooling, and proactive device support
2026-03-13 Add Twinr integrations, automations, and voice profile flows
2026-03-14 Refactor runtime and long-term memory flows
2026-03-15 Add orchestrator runtime and latency groundwork
2026-03-15 Speed up and ground orchestrator search lane
2026-03-17 some bugfixing and improvements to self-coding
    [__main__.py, common.py, config.py]
2026-03-18 addig ai camera and respeaker
2026-03-18 adding sensor fusion and better long term memory
2026-03-19 improving multi-sensor fusion and adding messenger integration
    [respeaker.scad, respeaker.stl]
2026-03-20 kws wakeword, 3d print case, gesture detection, personality refinement
    [main_panel.scad, main_panel.stl, thermal_printer.scad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]
2026-03-21 refinding wakeword, gesture recognicion, face recognition, sensor fusion and proactive engaging personality
2026-03-23 adding servo and custom servo kernel to make twinr rotate
2026-03-25 adding optional second pi as proxy for picam AI and servos (power, connectors, etc.)
2026-04-04 editing watchdogs, error/warning semantics, remote memory interaction...
    [config.py, controller.py, controller_geometry.py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]
